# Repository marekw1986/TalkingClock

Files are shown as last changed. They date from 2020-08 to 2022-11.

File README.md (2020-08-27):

# TalkingClock

## Overwiev
This is repository of firmware for Talking Clock project. 
It uses vintage parts, such as WDC65C02 CPU, M6242B RTC, MC6840 timer or R65C51 UART. 
It also consists SP0256-AL2 chip, providing retro speach synthesis capability.

This project is still in development.

## Required tools
You need [cc65](https://github.com/cc65/cc65) to build this project.
Additionaly there are two PLD files, consisting descriptions of address decoders for GAL chips used in this project. 
To synthesise them you need [GalAsm](https://github.com/daveho/GALasm).

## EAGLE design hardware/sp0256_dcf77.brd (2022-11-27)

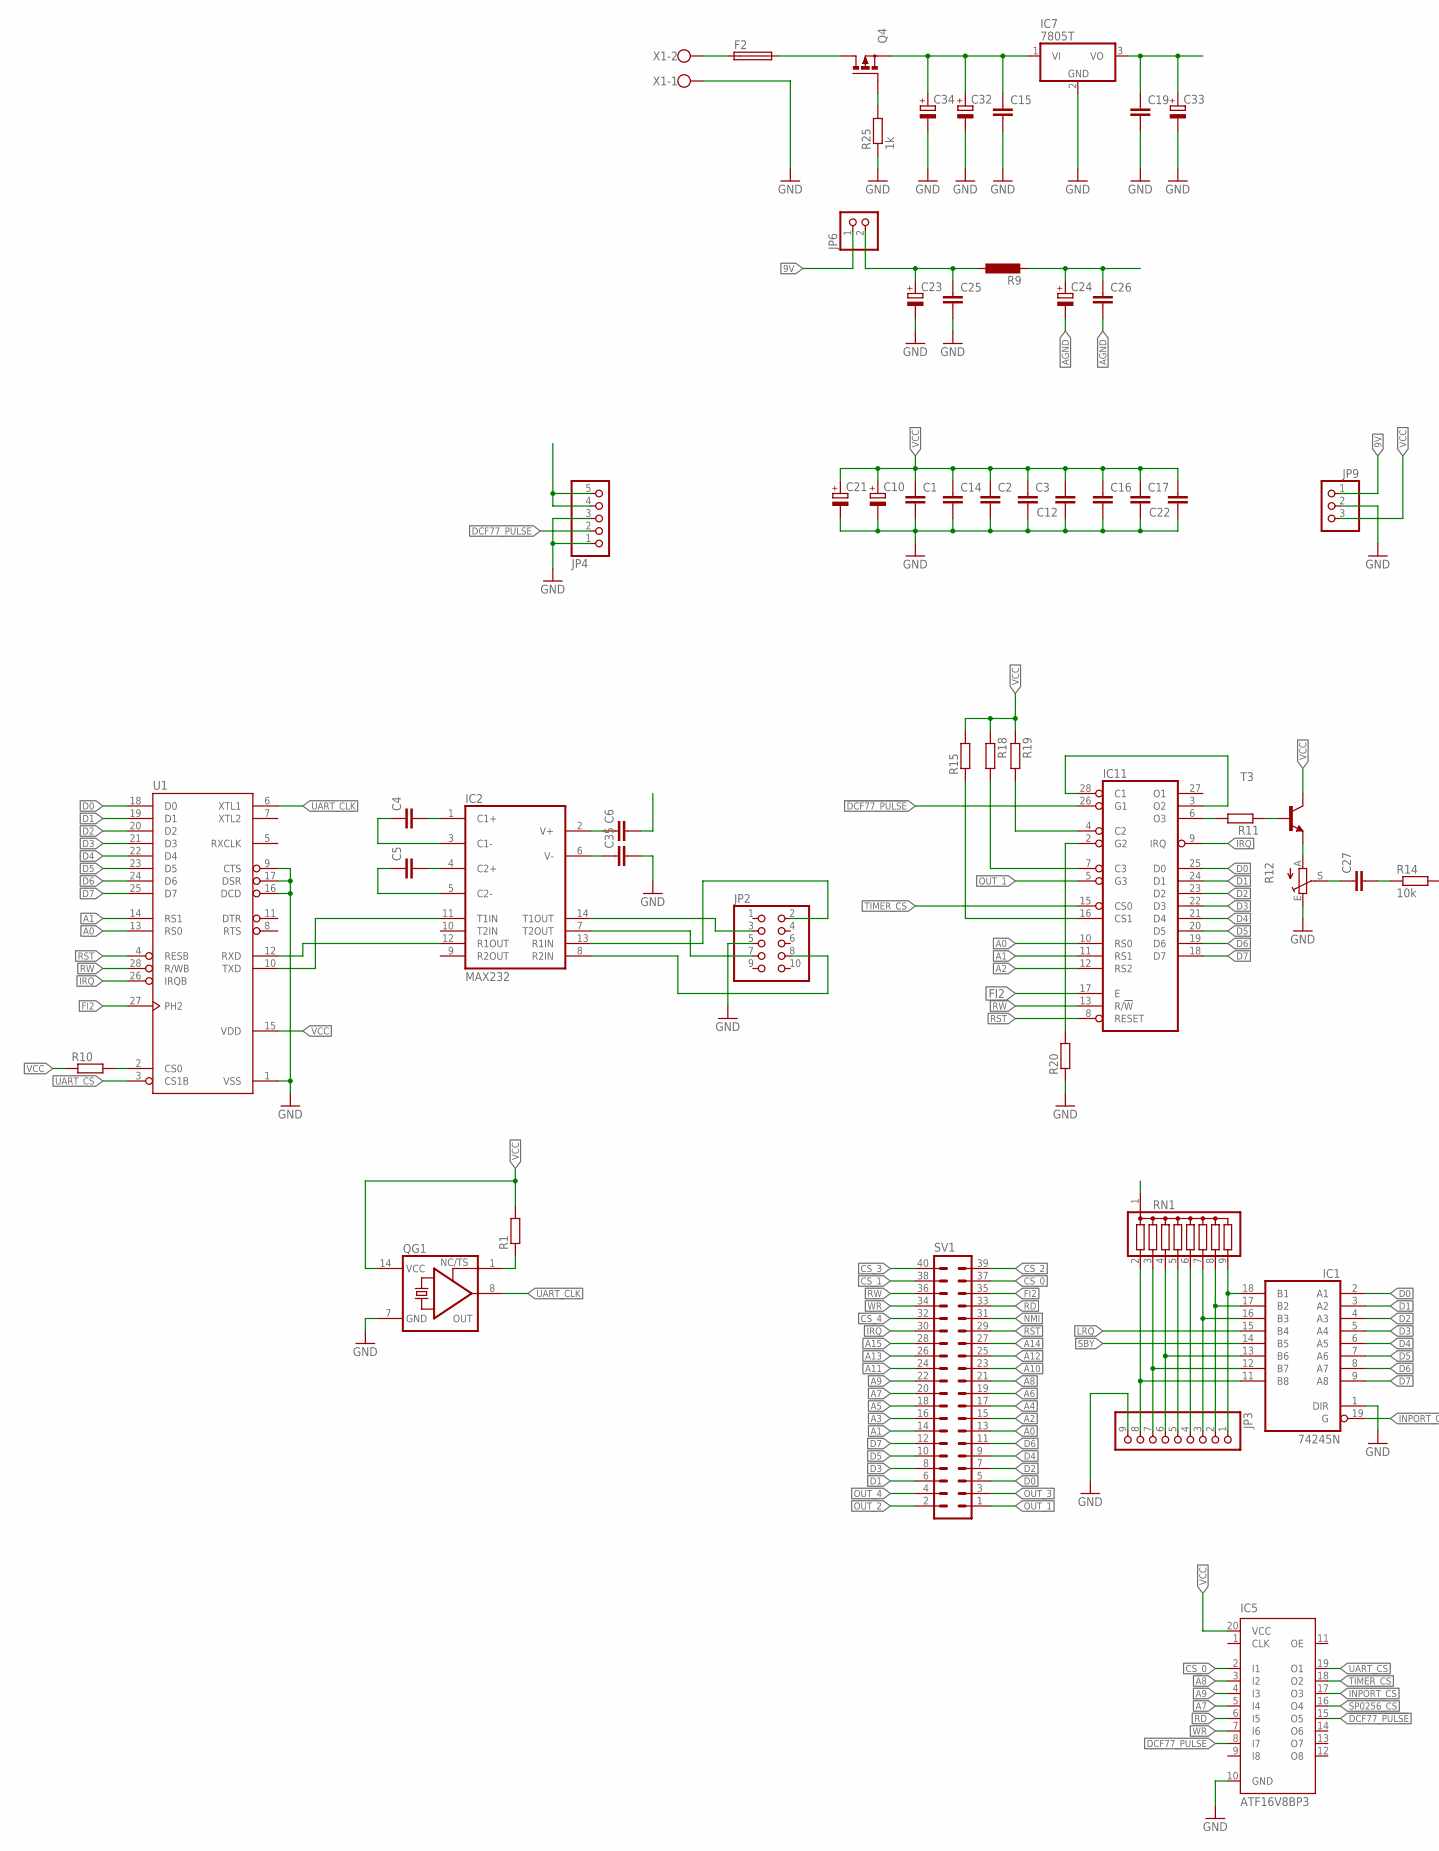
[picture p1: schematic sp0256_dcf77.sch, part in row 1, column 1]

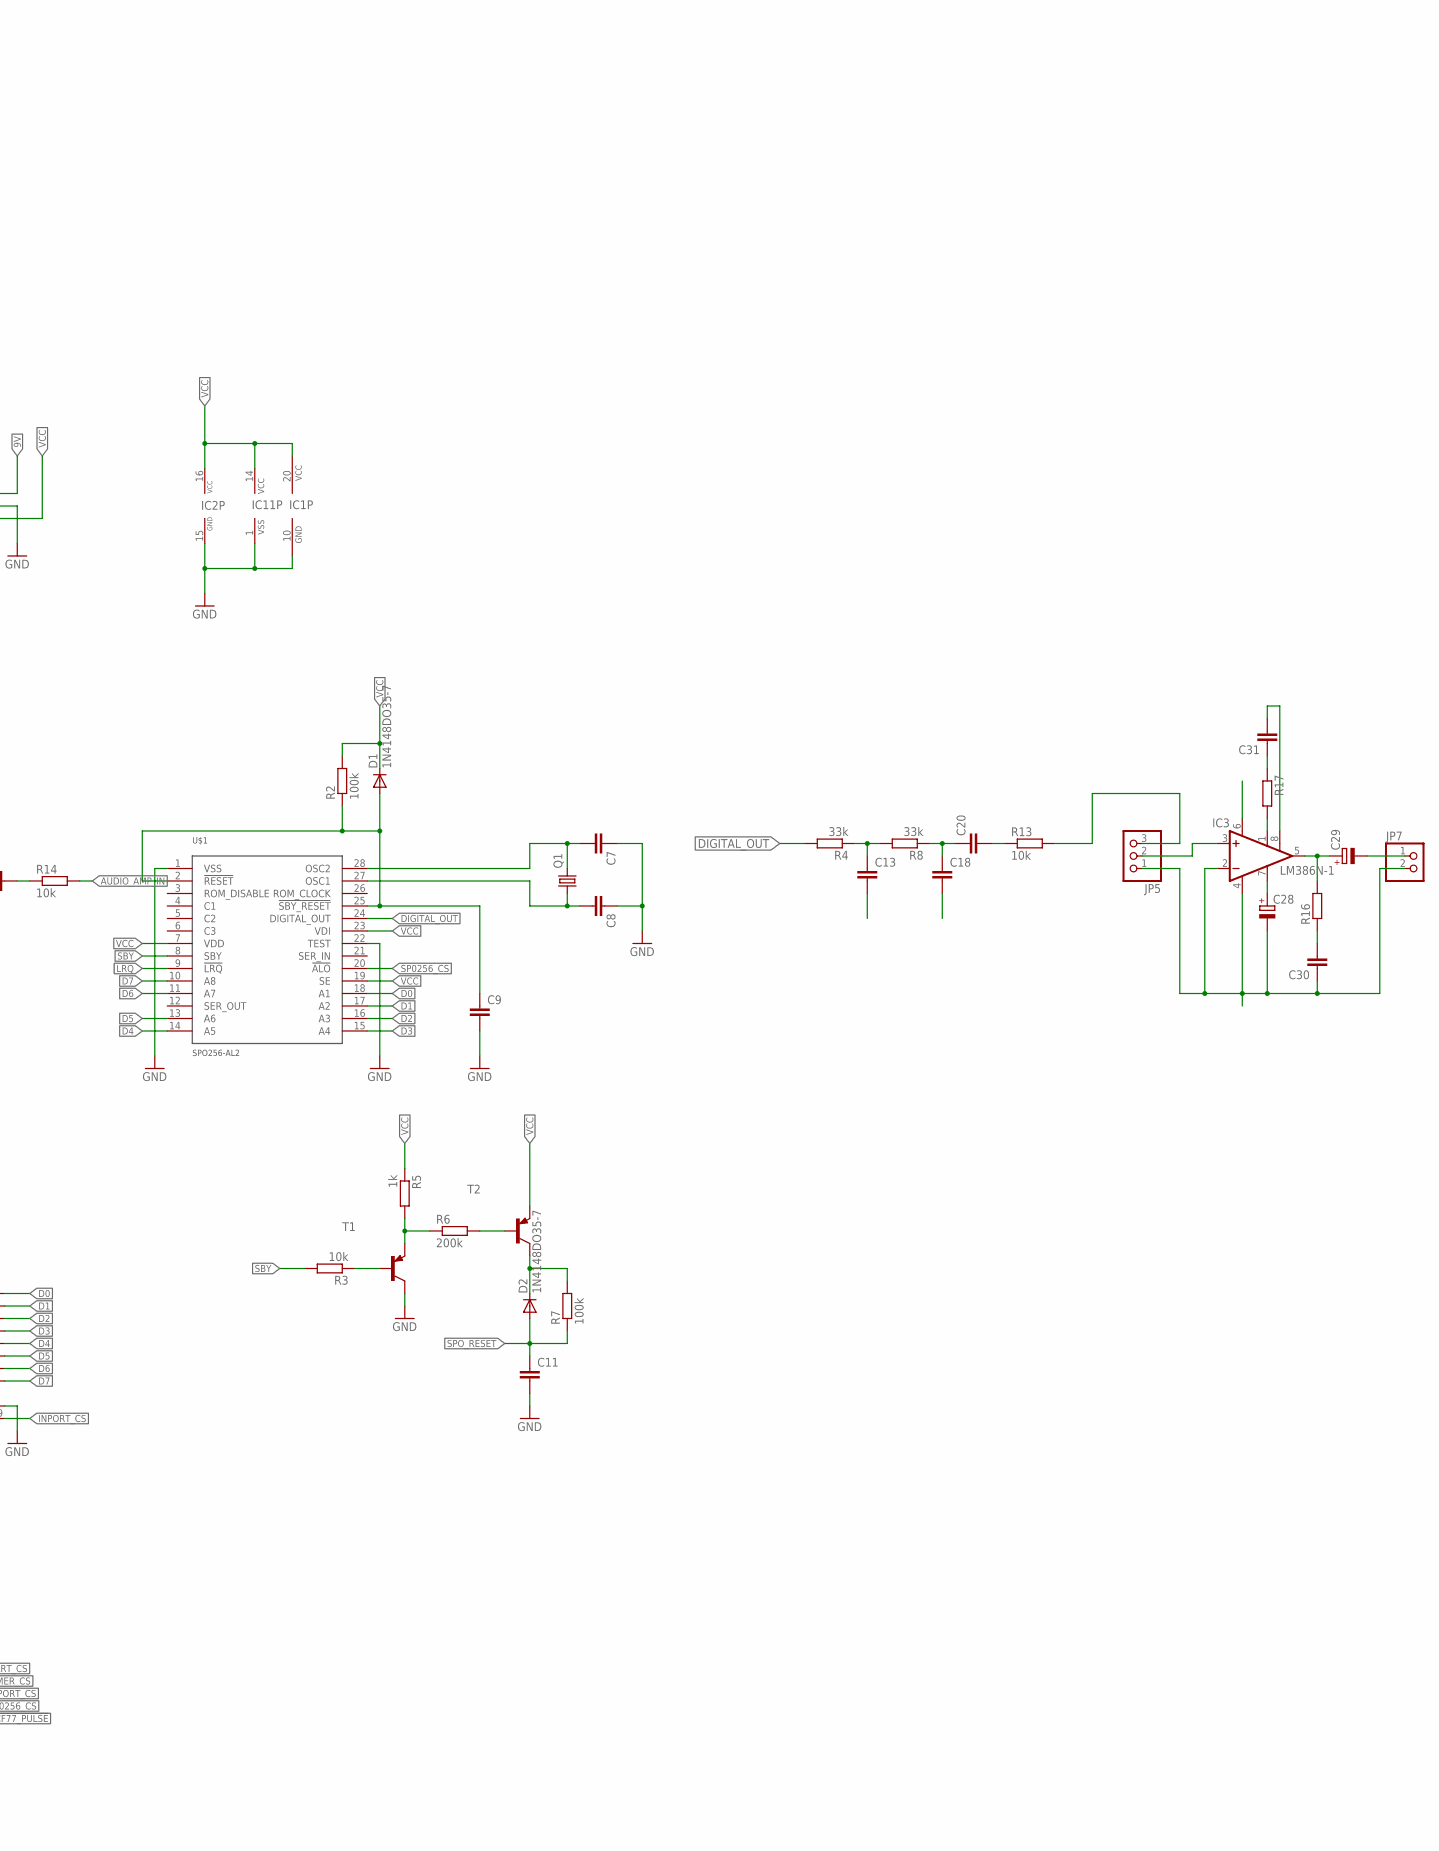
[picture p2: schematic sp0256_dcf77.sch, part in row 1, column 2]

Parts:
C1, C2, C3, C14, C15, C16, C17, C19, C25, C26: C-EUC1206; C1206
C4, C5, C6, C7, C8, C9, C11, C12, C13, C18, C20, C22, C27, C30, C31, C35: C-EUC0603; C0603
C10, C23, C24, C29, C32, C33, C34: CPOL-EUE5-10.5; E5-10,5
C21, C28: CPOL-EUSMCB; SMC_B
D1, D2: 1N4148DO35-7; DO35-7
F2: SH22,5; MPN 0031.8201
IC1: 74245N; DIL20
IC2: MAX232; DIL16
IC3: LM386N-1; DIL08
IC5: ATF16V8BP3; DIL20
IC7: 7805T; TO220H
IC11: 6840; DIL28
JP2: PINHD-2X5; 2X05
JP3: PINHD-1X9; 1X09
JP4: PINHD-1X5; 1X05
JP5: PINHD-1X3; 1X03
JP6, JP7: PINHD-1X2; 1X02
JP9: PINHD-1X3/90; 1X03/90
Q1: CRYSTALHC49U-V; HC49U-V
Q4: P-MOSFET-SO8; SO-08
QG1: XO-14; DIL14S
R1: R-EU_R1206; R1206
R2, R7: 100k; 0204/7
R3: 10k; 0204/7
R4, R8: 33k; 0204/7
R5: 1k; 0204/5
R6: 200k; R0603
R9: L-EU0204/7; 0204/7
R10, R15, R16, R18, R19, R20: R-EU_R0603; R0603
R11, R17: R-EU_0204/7; 0204/7
R12: TRIM_EU-CA6V; CA6V
R13, R14: 10k; R0603
R25: 1k; R0603
RN1: G08R; SIL9
SV1: ML40L
T1, T2: MPS2907A-PNP-TO92-CBE; TO92-CBE
T3: BC550-NPN-TO92-CBE; TO92-CBE
U1: G65SC51P; DIP-28
U$1: SPO256-AL2; DIL28
X1: W237-102

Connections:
9V: C15.1, C32.+, C34.+, IC7.1 (VI), JP6.1, JP9.1, Q4.1 (S), Q4.2 (S), Q4.3 (S)
9V_SW: C23.+, C25.1, JP6.2, R9.1
!DCF77_PULSE: IC5.15 (O5), IC11.26 (G1)
A0: IC11.10 (RS0), SV1.13, U1.13 (RS0)
A1: IC11.11 (RS1), SV1.14, U1.14 (RS1)
A2: IC11.12 (RS2), SV1.15
A3: SV1.16
A4: SV1.17
A5: SV1.18
A6: SV1.19
A7: IC5.5 (I4), SV1.20
A8: IC5.3 (I2), SV1.21
A9: IC5.4 (I3), SV1.22
A10: SV1.23
A11: SV1.24
A12: SV1.25
A13: SV1.26
A14: SV1.27
A15: SV1.28
AGND: C13.2, C18.2, C24.-, C26.2, C28.-, C30.1, IC3.2 (-IN), IC3.4 (GND), JP5.1, JP7.2
AUDIO_AMP_IN: JP5.3, R13.2, R14.2
AVCC: C24.+, C26.1, IC3.6 (VS), R9.2
CS_0: IC5.2 (I1), SV1.37
CS_1: SV1.38
CS_2: SV1.39
CS_3: SV1.40
CS_4: SV1.32
D0: IC1.2 (A1), IC11.25 (D0), SV1.5, U1.18 (D0), U$1.18 (A1)
D1: IC1.3 (A2), IC11.24 (D1), SV1.6, U1.19 (D1), U$1.17 (A2)
D2: IC1.4 (A3), IC11.23 (D2), SV1.7, U1.20 (D2), U$1.16 (A3)
D3: IC1.5 (A4), IC11.22 (D3), SV1.8, U1.21 (D3), U$1.15 (A4)
D4: IC1.6 (A5), IC11.21 (D4), SV1.9, U1.22 (D4), U$1.14 (A5)
D5: IC1.7 (A6), IC11.20 (D5), SV1.10, U1.23 (D5), U$1.13 (A6)
D6: IC1.8 (A7), IC11.19 (D6), SV1.11, U1.24 (D6), U$1.11 (A7)
D7: IC1.9 (A8), IC11.18 (D7), SV1.12, U1.25 (D7), U$1.10 (A8)
DCF77_PULSE: IC5.8 (I7), JP4.2
DIGITAL_OUT: R4.2, U$1.24 (DIGITAL_OUT)
FI2: IC11.17 (E), SV1.35, U1.27 (PH2)
GATE2: IC11.2 (G2), R20.2
GND: C1.2, C2.2, C3.2, C7.1, C8.1, C9.2, C10.-, C11.2, C12.1, C14.2, C15.2, C16.2, C17.2, C19.2, C21.-, C22.1, C23.-, C25.2, C32.-, C33.-, C34.-, C35.2, IC1.1 (DIR), IC1.10 (GND), IC2.15 (GND), IC5.10 (GND), IC7.2 (GND), IC11.1 (VSS), JP2.5, JP3.9, JP4.1, JP4.3, JP9.2, QG1.7 (GND), R12.E, R20.1, R25.1, T1.C, U1.1 (VSS), U1.9 (CTS), U1.16 (DCD), U1.17 (DSR), U$1.1 (VSS), U$1.22 (TEST), X1.1
INPORT_CS: IC1.19 (G), IC5.17 (O3)
IRQ: IC11.9 (IRQ), SV1.30, U1.26 (IRQB)
LRQ: IC1.15 (B4), U$1.9 (!LRQ)
unnamed: Q4.4 (G), R25.2
unnamed: IC11.3 (O2), IC11.28 (C1)
unnamed: C35.1, IC2.6 (V-)
unnamed: QG1.1 (TS), R1.1
unnamed: C7.2, Q1.2, U$1.28 (OSC2)
unnamed: C8.2, Q1.1, U$1.27 (OSC1)
unnamed: R3.1, T1.B
unnamed: C4.2, IC2.1 (C1+)
unnamed: C5.2, IC2.4 (C2+)
unnamed: C5.1, IC2.5 (C2-)
unnamed: C4.1, IC2.3 (C1-)
unnamed: C6.1, IC2.2 (V+)
unnamed: IC1.18 (B1), JP3.1, RN1.9
unnamed: IC1.17 (B2), JP3.2, RN1.8
unnamed: IC1.16 (B3), JP3.3, RN1.7
unnamed: C13.1, R4.1, R8.2
unnamed: JP3.5, RN1.5
unnamed: IC1.13 (B6), JP3.6, RN1.4
unnamed: IC1.12 (B7), JP3.7, RN1.3
unnamed: IC1.11 (B8), JP3.8, RN1.2
unnamed: JP3.4, RN1.6
unnamed: R10.2, U1.2 (CS0)
unnamed: R5.2, R6.1, T1.E
unnamed: R6.2, T2.B
unnamed: D2.C, R7.2, T2.C
unnamed: IC11.16 (CS1), R15.1
unnamed: C18.1, C20.1, R8.1
unnamed: C28.+, IC3.7 (BYPASS)
unnamed: IC11.7 (C3), R18.2
unnamed: IC11.6 (O3), R11.2
unnamed: R11.1, T3.B
unnamed: R12.A, T3.E
unnamed: C27.1, R12.S
unnamed: C27.2, R14.1
unnamed: C20.2, R13.1
unnamed: IC3.3 (+IN), JP5.2
unnamed: C29.+, IC3.5 (OUT), R16.2
unnamed: C30.2, R16.1
unnamed: IC3.1 (GAIN), R17.2
unnamed: C31.1, R17.1
unnamed: C31.2, IC3.8 (GAIN)
unnamed: C29.-, JP7.1
unnamed: IC11.4 (C2), R19.2
unnamed: F2.2, Q4.5 (D), Q4.6 (D), Q4.7 (D), Q4.8 (D)
unnamed: F2.1, X1.2
NMI: SV1.31
OUT_1: IC11.5 (G3), SV1.1
OUT_2: SV1.2
OUT_3: SV1.3
OUT_4: SV1.4
RD: IC5.6 (I5), SV1.33
RST: IC11.8 (RESET), SV1.29, U1.4 (RESB)
RS_CTS: IC2.8 (R2IN), JP2.8
RS_RTS: IC2.7 (T2OUT), JP2.7
RS_RXD: IC2.13 (R1IN), JP2.2
RS_TXD: IC2.14 (T1OUT), JP2.3
RW: IC11.13 (R/!W), SV1.36, U1.28 (R/WB)
RXD_TTL: IC2.12 (R1OUT), U1.12 (RXD)
SBY: IC1.14 (B5), R3.2, U$1.8 (SBY)
SP0256_CS: IC5.16 (O4), U$1.20 (!ALO)
SPO_RESET: C9.1, C11.1, D1.A, D2.A, R2.1, R7.1, U$1.2 (!RESET), U$1.25 (!SBY_RESET)
TIMER_CS: IC5.18 (O2), IC11.15 (CS0)
TXD_TTL: IC2.11 (T1IN), U1.10 (TXD)
UART_CLK: QG1.8 (OUT), U1.6 (XTL1)
UART_CS: IC5.19 (O1), U1.3 (CS1B)
VCC: C1.1, C2.1, C3.1, C6.2, C10.+, C12.2, C14.1, C16.1, C17.1, C19.1, C21.+, C22.2, C33.+, D1.C, IC1.20 (VCC), IC2.16 (VCC), IC5.20 (VCC), IC7.3 (VO), IC11.14 (VCC), JP4.4, JP4.5, JP9.3, QG1.14 (VCC), R1.2, R2.2, R5.1, R10.1, R15.2, R18.1, R19.1, RN1.1, T2.E, T3.C, U1.15 (VDD), U$1.7 (VDD), U$1.19 (SE), U$1.23 (VDI)
WR: IC5.7 (I6), SV1.34

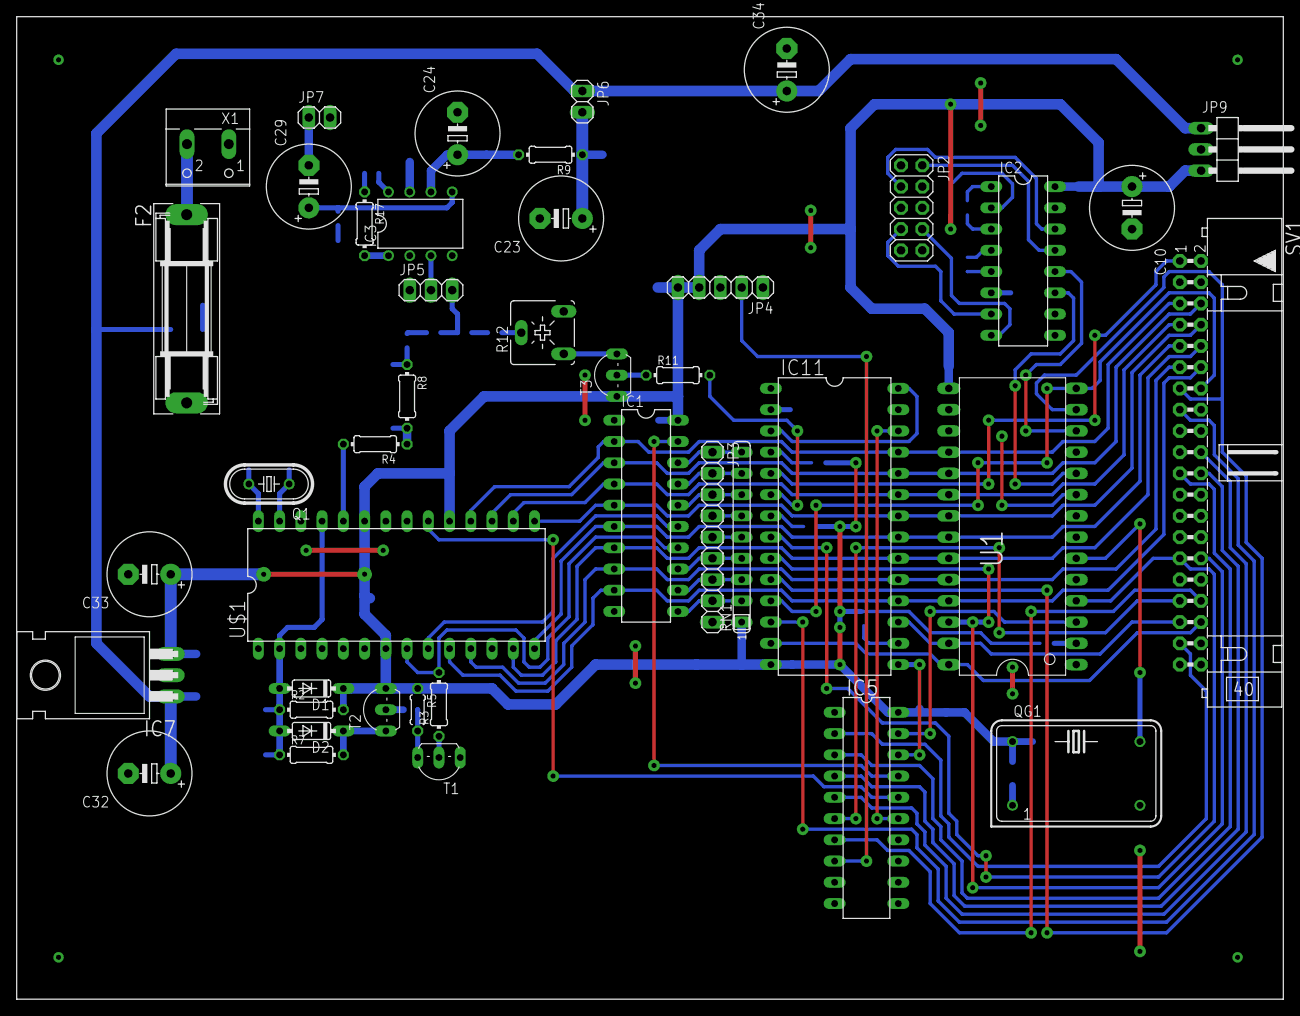
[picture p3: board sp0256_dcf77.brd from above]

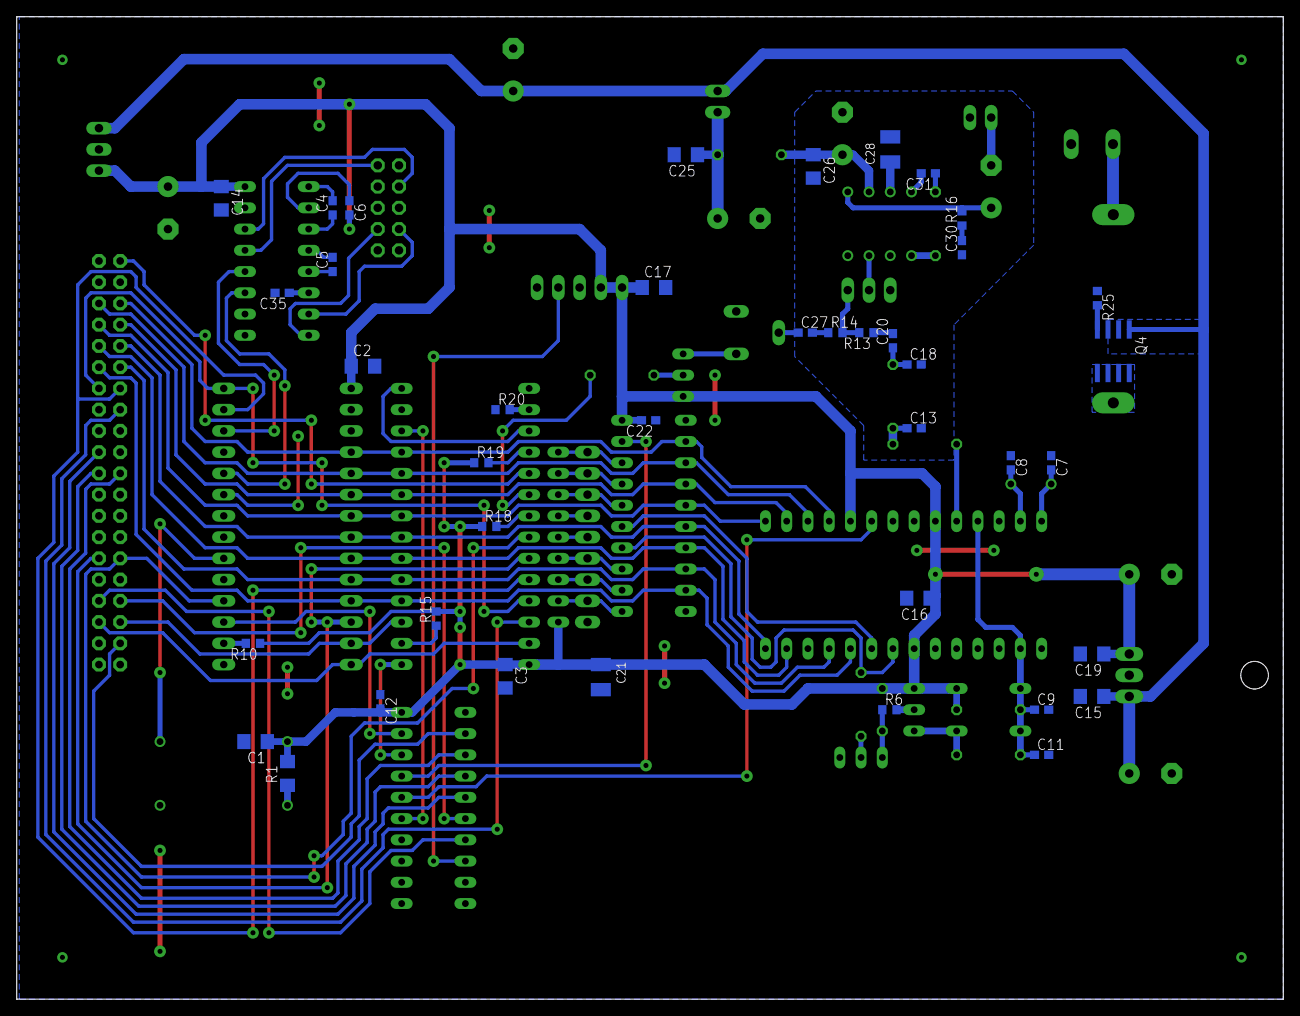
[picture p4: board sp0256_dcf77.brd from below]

Board: 2 copper layers, 151.4 x 117.5 mm, 83 parts (40 on the bottom side), 92 nets.

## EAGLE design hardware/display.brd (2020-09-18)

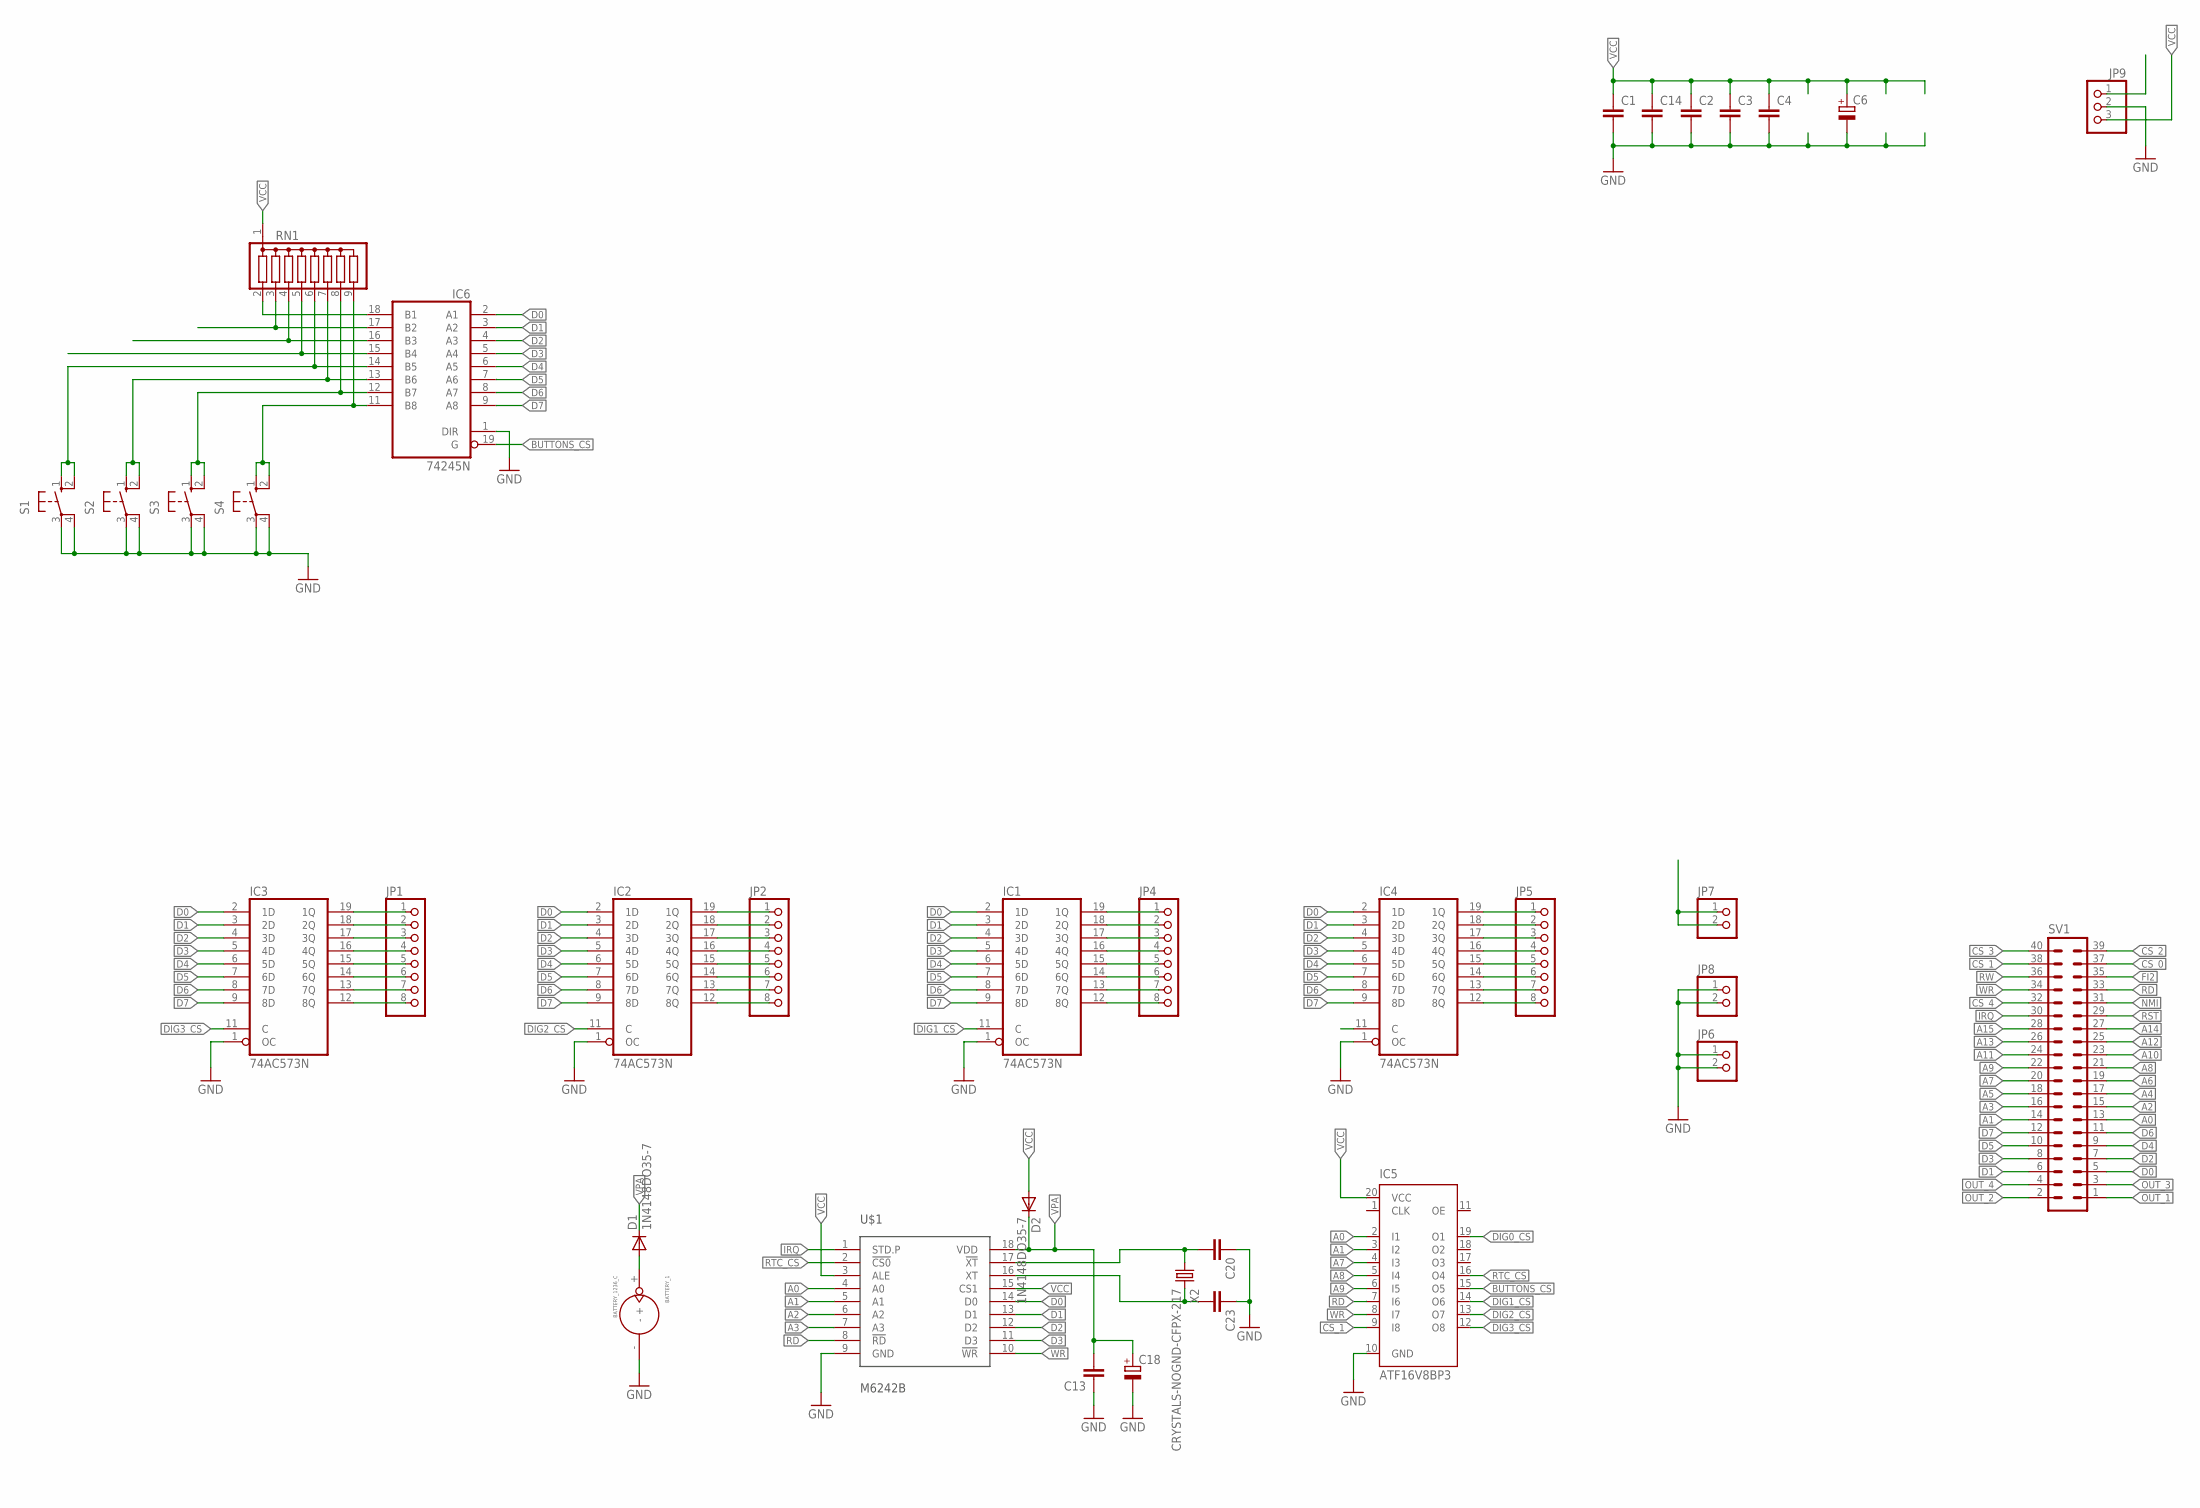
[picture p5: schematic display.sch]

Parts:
BATTERY_1: BATTERY_1236_C
C1, C2, C3, C4, C14: C-EUC1206; C1206
C6: CPOL-EUSMCD; SMC_D
C13, C20, C23: C-EUC0603; C0603
C18: CPOL-EUSMCB; SMC_B
D1, D2: 1N4148DO35-7; DO35-7
IC1, IC2, IC3, IC4: 74AC573N; DIL20
IC5: ATF16V8BP3; DIL20
IC6: 74245N; DIL20
JP1, JP2, JP4, JP5: PINHD-1X8; 1X08
JP6, JP7, JP8: PINHD-1X2; 1X02
JP9: PINHD-1X3/90; 1X03/90
RN1: G08R; SIL9
S1, S2, S3, S4: 40-XX; B3F-40XX
SV1: ML40L
U$1: M6242B; DIL18
X2: CRYSTALS-NOGND-CFPX-217; 3.2X1.5-2-PAD

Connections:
9V: JP7.1, JP7.2, JP9.1
A0: IC5.2 (I1), SV1.13, U$1.4 (A0)
A1: IC5.3 (I2), SV1.14, U$1.5 (A1)
A2: SV1.15, U$1.6 (A2)
A3: SV1.16, U$1.7 (A3)
A4: SV1.17
A5: SV1.18
A6: SV1.19
A7: IC5.4 (I3), SV1.20
A8: IC5.5 (I4), SV1.21
A9: IC5.6 (I5), SV1.22
A10: SV1.23
A11: SV1.24
A12: SV1.25
A13: SV1.26
A14: SV1.27
A15: SV1.28
BUTTONS_CS: IC5.15 (O5), IC6.19 (G)
CS_0: SV1.37
CS_1: IC5.9 (I8), SV1.38
CS_2: SV1.39
CS_3: SV1.40
CS_4: SV1.32
D0: IC1.2 (1D), IC2.2 (1D), IC3.2 (1D), IC4.2 (1D), IC6.2 (A1), SV1.5, U$1.14 (D0)
D1: IC1.3 (2D), IC2.3 (2D), IC3.3 (2D), IC4.3 (2D), IC6.3 (A2), SV1.6, U$1.13 (D1)
D2: IC1.4 (3D), IC2.4 (3D), IC3.4 (3D), IC4.4 (3D), IC6.4 (A3), SV1.7, U$1.12 (D2)
D3: IC1.5 (4D), IC2.5 (4D), IC3.5 (4D), IC4.5 (4D), IC6.5 (A4), SV1.8, U$1.11 (D3)
D4: IC1.6 (5D), IC2.6 (5D), IC3.6 (5D), IC4.6 (5D), IC6.6 (A5), SV1.9
D5: IC1.7 (6D), IC2.7 (6D), IC3.7 (6D), IC4.7 (6D), IC6.7 (A6), SV1.10
D6: IC1.8 (7D), IC2.8 (7D), IC3.8 (7D), IC4.8 (7D), IC6.8 (A7), SV1.11
D7: IC1.9 (8D), IC2.9 (8D), IC3.9 (8D), IC4.9 (8D), IC6.9 (A8), SV1.12
DIG0_CS: IC4.11 (C), IC5.19 (O1)
DIG1_CS: IC1.11 (C), IC5.14 (O6)
DIG2_CS: IC2.11 (C), IC5.13 (O7)
DIG3_CS: IC3.11 (C), IC5.12 (O8)
FI2: SV1.35
GND: BATTERY_1.-, C1.2, C2.2, C3.2, C4.2, C6.-, C13.1, C14.2, C18.-, C20.1, C23.1, IC1.1 (OC), IC1.10 (GND), IC2.1 (OC), IC2.10 (GND), IC3.1 (OC), IC3.10 (GND), IC4.1 (OC), IC4.10 (GND), IC5.10 (GND), IC6.1 (DIR), IC6.10 (GND), JP6.1, JP6.2, JP8.1, JP8.2, JP9.2, S1.3, S1.4 (P1), S2.3, S2.4 (P1), S3.3, S3.4 (P1), S4.3, S4.4 (P1), U$1.9 (GND)
IRQ: SV1.30, U$1.1 (STD.P)
unnamed: IC3.12 (8Q), JP1.8
unnamed: IC3.13 (7Q), JP1.7
unnamed: IC3.14 (6Q), JP1.6
unnamed: IC3.19 (1Q), JP1.1
unnamed: IC3.18 (2Q), JP1.2
unnamed: IC3.17 (3Q), JP1.3
unnamed: IC3.16 (4Q), JP1.4
unnamed: IC3.15 (5Q), JP1.5
unnamed: IC2.17 (3Q), JP2.3
unnamed: IC2.18 (2Q), JP2.2
unnamed: IC2.19 (1Q), JP2.1
unnamed: IC2.16 (4Q), JP2.4
unnamed: IC2.15 (5Q), JP2.5
unnamed: IC2.14 (6Q), JP2.6
unnamed: IC2.13 (7Q), JP2.7
unnamed: IC2.12 (8Q), JP2.8
unnamed: IC1.19 (1Q), JP4.1
unnamed: IC1.18 (2Q), JP4.2
unnamed: IC1.17 (3Q), JP4.3
unnamed: IC1.16 (4Q), JP4.4
unnamed: IC1.15 (5Q), JP4.5
unnamed: IC1.14 (6Q), JP4.6
unnamed: IC1.13 (7Q), JP4.7
unnamed: IC1.12 (8Q), JP4.8
unnamed: IC4.17 (3Q), JP5.3
unnamed: IC4.19 (1Q), JP5.1
unnamed: IC4.18 (2Q), JP5.2
unnamed: IC4.16 (4Q), JP5.4
unnamed: IC4.15 (5Q), JP5.5
unnamed: IC4.14 (6Q), JP5.6
unnamed: IC4.13 (7Q), JP5.7
unnamed: IC4.12 (8Q), JP5.8
unnamed: BATTERY_1.+, D1.A
unnamed: IC6.14 (B5), RN1.6, S1.1 (S), S1.2 (S1)
unnamed: IC6.13 (B6), RN1.7, S2.1 (S), S2.2 (S1)
unnamed: IC6.12 (B7), RN1.8, S3.1 (S), S3.2 (S1)
unnamed: IC6.11 (B8), RN1.9, S4.1 (S), S4.2 (S1)
NMI: SV1.31
OUT_1: SV1.1
OUT_2: SV1.2
OUT_3: SV1.3
OUT_4: SV1.4
RD: IC5.7 (I6), SV1.33, U$1.8 (!RD)
RST: SV1.29
RTC_CS: IC5.16 (O4), U$1.2 (!CS0)
RW: SV1.36
S1: IC6.15 (B4), RN1.5
S2: IC6.16 (B3), RN1.4
S3: IC6.17 (B2), RN1.3
S4: IC6.18 (B1), RN1.2
SOSCI: C20.2, U$1.17 (!XT), X2.1
SOSCO: C23.2, U$1.16 (XT), X2.2
VCC: C1.1, C2.1, C3.1, C4.1, C6.+, C14.1, D2.A, IC1.20 (VCC), IC2.20 (VCC), IC3.20 (VCC), IC4.20 (VCC), IC5.20 (VCC), IC6.20 (VCC), JP9.3, RN1.1, U$1.3 (ALE), U$1.15 (CS1)
VPA: C13.2, C18.+, D1.C, D2.C, U$1.18 (VDD)
WR: IC5.8 (I7), SV1.34, U$1.10 (!WR)

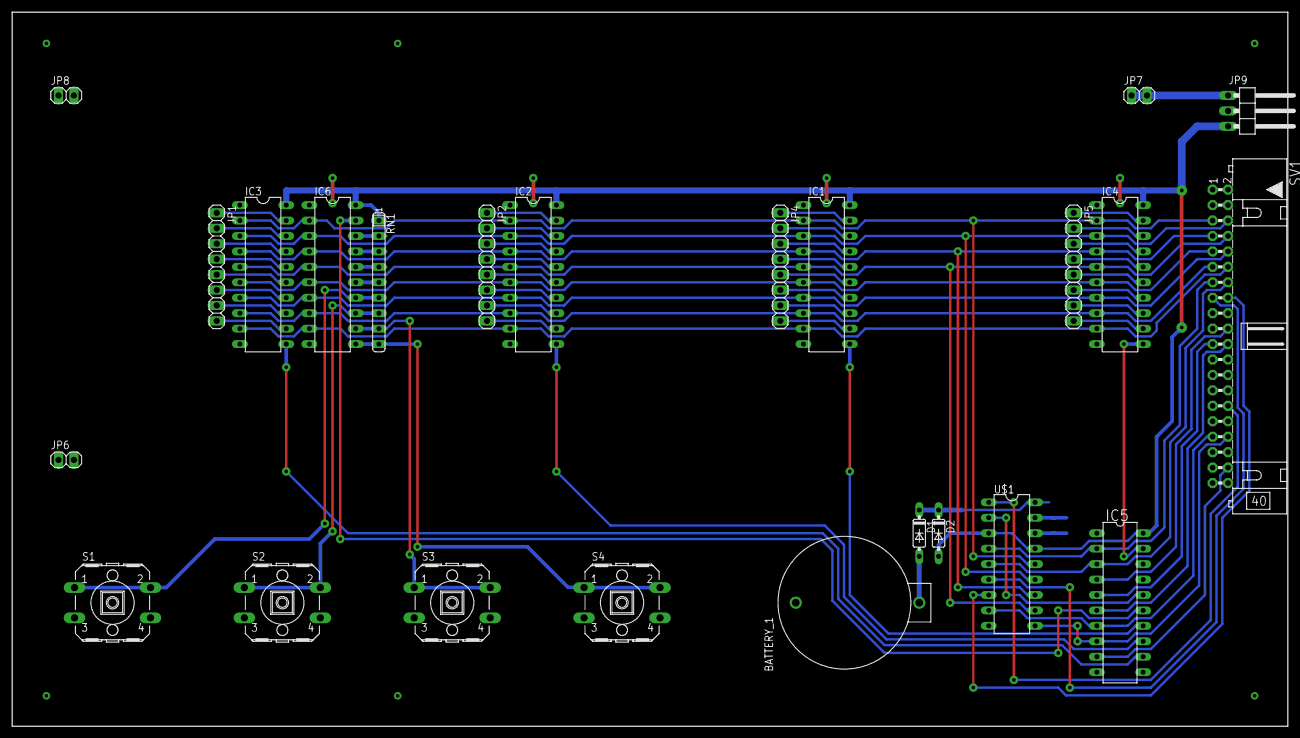
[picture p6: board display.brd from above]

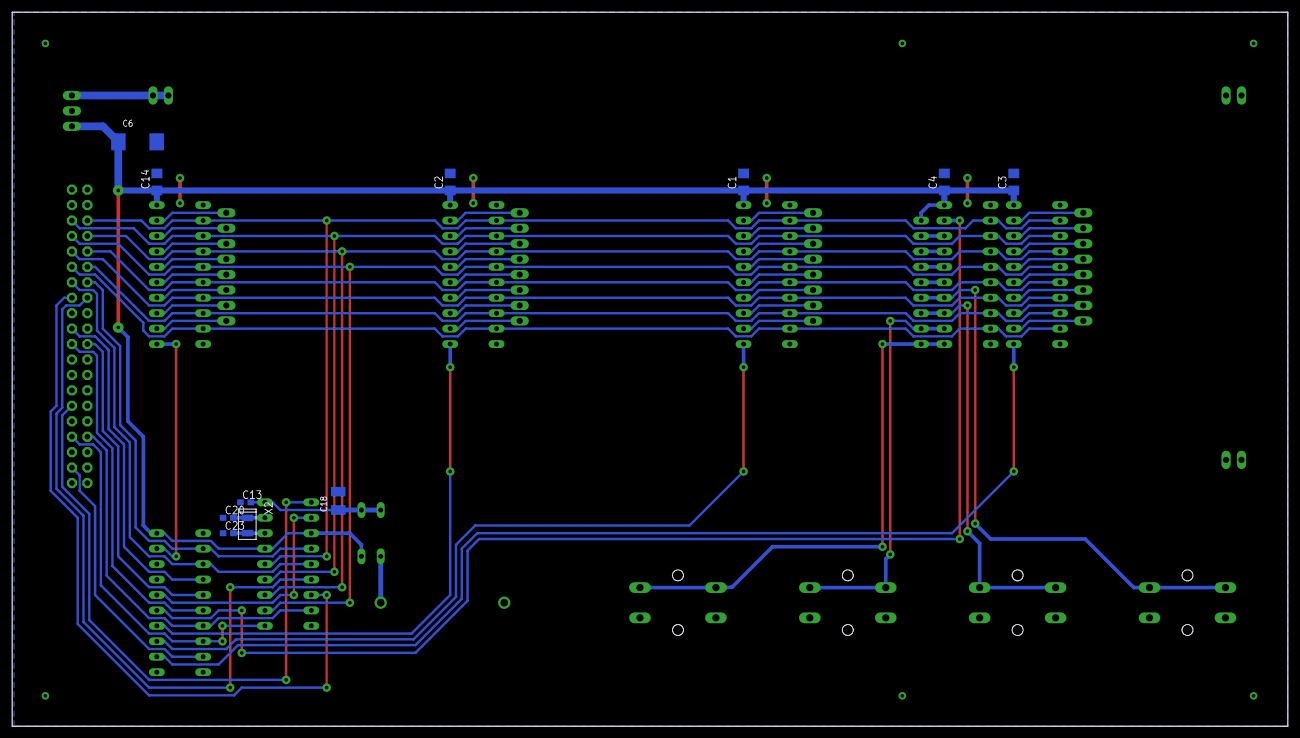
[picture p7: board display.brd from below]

Board: 2 copper layers, 209.9 x 117.5 mm, 35 parts (11 on the bottom side), 72 nets.

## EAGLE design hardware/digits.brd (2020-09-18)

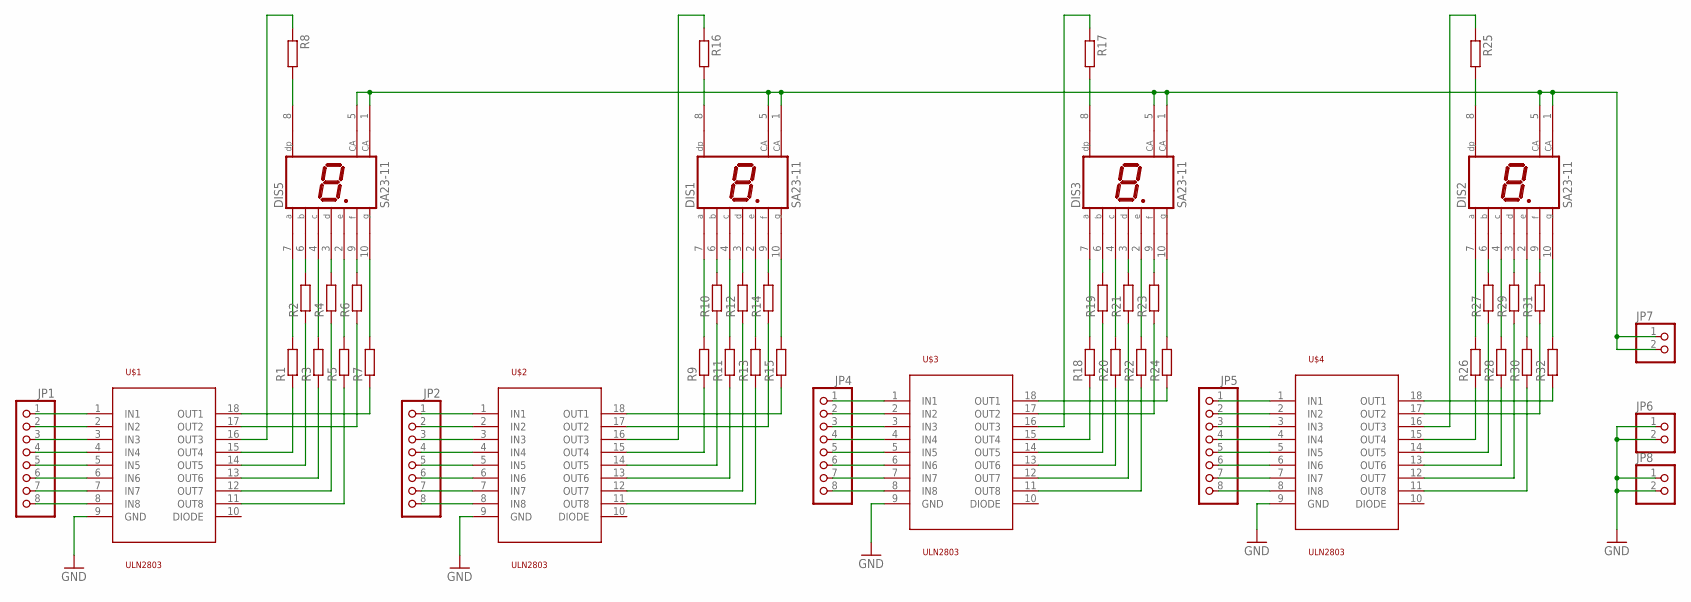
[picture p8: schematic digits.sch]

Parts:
DIS1, DIS2, DIS3, DIS5: SA23-11; SX23-XX
JP1, JP2, JP4, JP5: PINHD-1X8; 1X08
JP6, JP7, JP8: PINHD-1X2; 1X02
R1, R2, R6, R7, R8, R9, R10, R14, R15, R16, R17, R18, R19, R23, R24, R25, R26, R27, R31, R32: R-EU_R0603; R0603
R3, R4, R5, R11, R12, R13, R20, R21, R22, R28, R29, R30: R-EU_0204/7; 0204/7
U$1, U$2, U$3, U$4: ULN2803; SO18L

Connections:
9V: DIS1.1 (CA), DIS1.5 (CA), DIS2.1 (CA), DIS2.5 (CA), DIS3.1 (CA), DIS3.5 (CA), DIS5.1 (CA), DIS5.5 (CA), JP7.1, JP7.2
GND: JP6.1, JP6.2, JP8.1, JP8.2, U$1.9 (GND), U$2.9 (GND), U$3.9 (GND), U$4.9 (GND)
unnamed: DIS5.7 (A), R1.2
unnamed: DIS5.6 (B), R2.2
unnamed: JP1.8, U$1.8 (IN8)
unnamed: JP1.7, U$1.7 (IN7)
unnamed: JP1.6, U$1.6 (IN6)
unnamed: JP1.1, U$1.1 (IN1)
unnamed: JP1.2, U$1.2 (IN2)
unnamed: JP1.3, U$1.3 (IN3)
unnamed: JP1.4, U$1.4 (IN4)
unnamed: JP1.5, U$1.5 (IN5)
unnamed: DIS5.4 (C), R3.2
unnamed: DIS5.3 (D), R4.2
unnamed: DIS5.2 (E), R5.2
unnamed: DIS5.9 (F), R6.2
unnamed: DIS5.10 (G), R7.2
unnamed: DIS5.8 (DP), R8.2
unnamed: DIS1.7 (A), R9.2
unnamed: DIS1.4 (C), R11.2
unnamed: DIS1.2 (E), R13.2
unnamed: DIS1.10 (G), R15.2
unnamed: DIS1.6 (B), R10.2
unnamed: DIS1.3 (D), R12.2
unnamed: DIS1.9 (F), R14.2
unnamed: DIS1.8 (DP), R16.2
unnamed: DIS3.8 (DP), R17.2
unnamed: DIS3.7 (A), R18.2
unnamed: DIS3.4 (C), R20.2
unnamed: JP2.3, U$2.3 (IN3)
unnamed: JP2.2, U$2.2 (IN2)
unnamed: JP2.1, U$2.1 (IN1)
unnamed: JP2.4, U$2.4 (IN4)
unnamed: JP2.5, U$2.5 (IN5)
unnamed: JP2.6, U$2.6 (IN6)
unnamed: JP2.7, U$2.7 (IN7)
unnamed: JP2.8, U$2.8 (IN8)
unnamed: JP4.1, U$3.1 (IN1)
unnamed: DIS3.2 (E), R22.2
unnamed: JP4.2, U$3.2 (IN2)
unnamed: JP4.3, U$3.3 (IN3)
unnamed: DIS3.10 (G), R24.2
unnamed: DIS3.6 (B), R19.2
unnamed: DIS3.3 (D), R21.2
unnamed: DIS3.9 (F), R23.2
unnamed: DIS2.8 (DP), R25.2
unnamed: DIS2.7 (A), R26.2
unnamed: DIS2.4 (C), R28.2
unnamed: DIS2.2 (E), R30.2
unnamed: JP4.4, U$3.4 (IN4)
unnamed: JP4.5, U$3.5 (IN5)
unnamed: JP4.6, U$3.6 (IN6)
unnamed: JP4.7, U$3.7 (IN7)
unnamed: JP4.8, U$3.8 (IN8)
unnamed: DIS2.10 (G), R32.2
unnamed: DIS2.6 (B), R27.2
unnamed: DIS2.3 (D), R29.2
unnamed: DIS2.9 (F), R31.2
unnamed: R5.1, U$1.11 (OUT8)
unnamed: R4.1, U$1.12 (OUT7)
unnamed: R3.1, U$1.13 (OUT6)
unnamed: R2.1, U$1.14 (OUT5)
unnamed: JP5.3, U$4.3 (IN3)
unnamed: JP5.1, U$4.1 (IN1)
unnamed: JP5.2, U$4.2 (IN2)
unnamed: JP5.4, U$4.4 (IN4)
unnamed: JP5.5, U$4.5 (IN5)
unnamed: JP5.6, U$4.6 (IN6)
unnamed: JP5.7, U$4.7 (IN7)
unnamed: JP5.8, U$4.8 (IN8)
unnamed: R1.1, U$1.15 (OUT4)
unnamed: R8.1, U$1.16 (OUT3)
unnamed: R6.1, U$1.17 (OUT2)
unnamed: R7.1, U$1.18 (OUT1)
unnamed: R15.1, U$2.18 (OUT1)
unnamed: R14.1, U$2.17 (OUT2)
unnamed: R16.1, U$2.16 (OUT3)
unnamed: R9.1, U$2.15 (OUT4)
unnamed: R10.1, U$2.14 (OUT5)
unnamed: R11.1, U$2.13 (OUT6)
unnamed: R12.1, U$2.12 (OUT7)
unnamed: R13.1, U$2.11 (OUT8)
unnamed: R24.1, U$3.18 (OUT1)
unnamed: R23.1, U$3.17 (OUT2)
unnamed: R17.1, U$3.16 (OUT3)
unnamed: R18.1, U$3.15 (OUT4)
unnamed: R19.1, U$3.14 (OUT5)
unnamed: R20.1, U$3.13 (OUT6)
unnamed: R21.1, U$3.12 (OUT7)
unnamed: R22.1, U$3.11 (OUT8)
unnamed: R32.1, U$4.18 (OUT1)
unnamed: R31.1, U$4.17 (OUT2)
unnamed: R25.1, U$4.16 (OUT3)
unnamed: R26.1, U$4.15 (OUT4)
unnamed: R27.1, U$4.14 (OUT5)
unnamed: R28.1, U$4.13 (OUT6)
unnamed: R29.1, U$4.12 (OUT7)
unnamed: R30.1, U$4.11 (OUT8)

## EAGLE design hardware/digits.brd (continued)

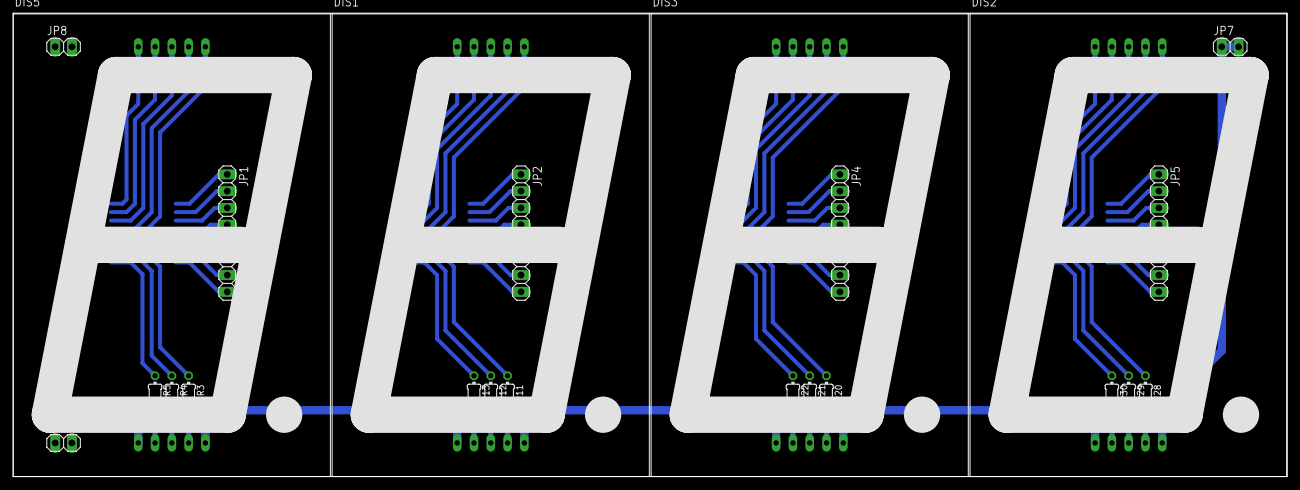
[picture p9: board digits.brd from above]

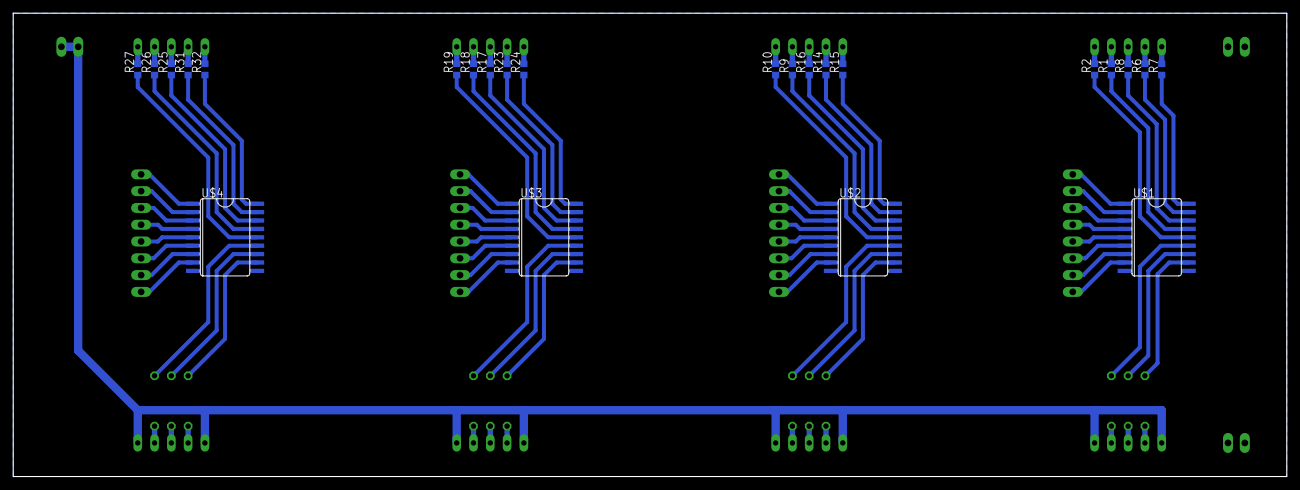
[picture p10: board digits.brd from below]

Board: 2 copper layers, 192.7 x 70.1 mm, 47 parts (24 on the bottom side), 98 nets.

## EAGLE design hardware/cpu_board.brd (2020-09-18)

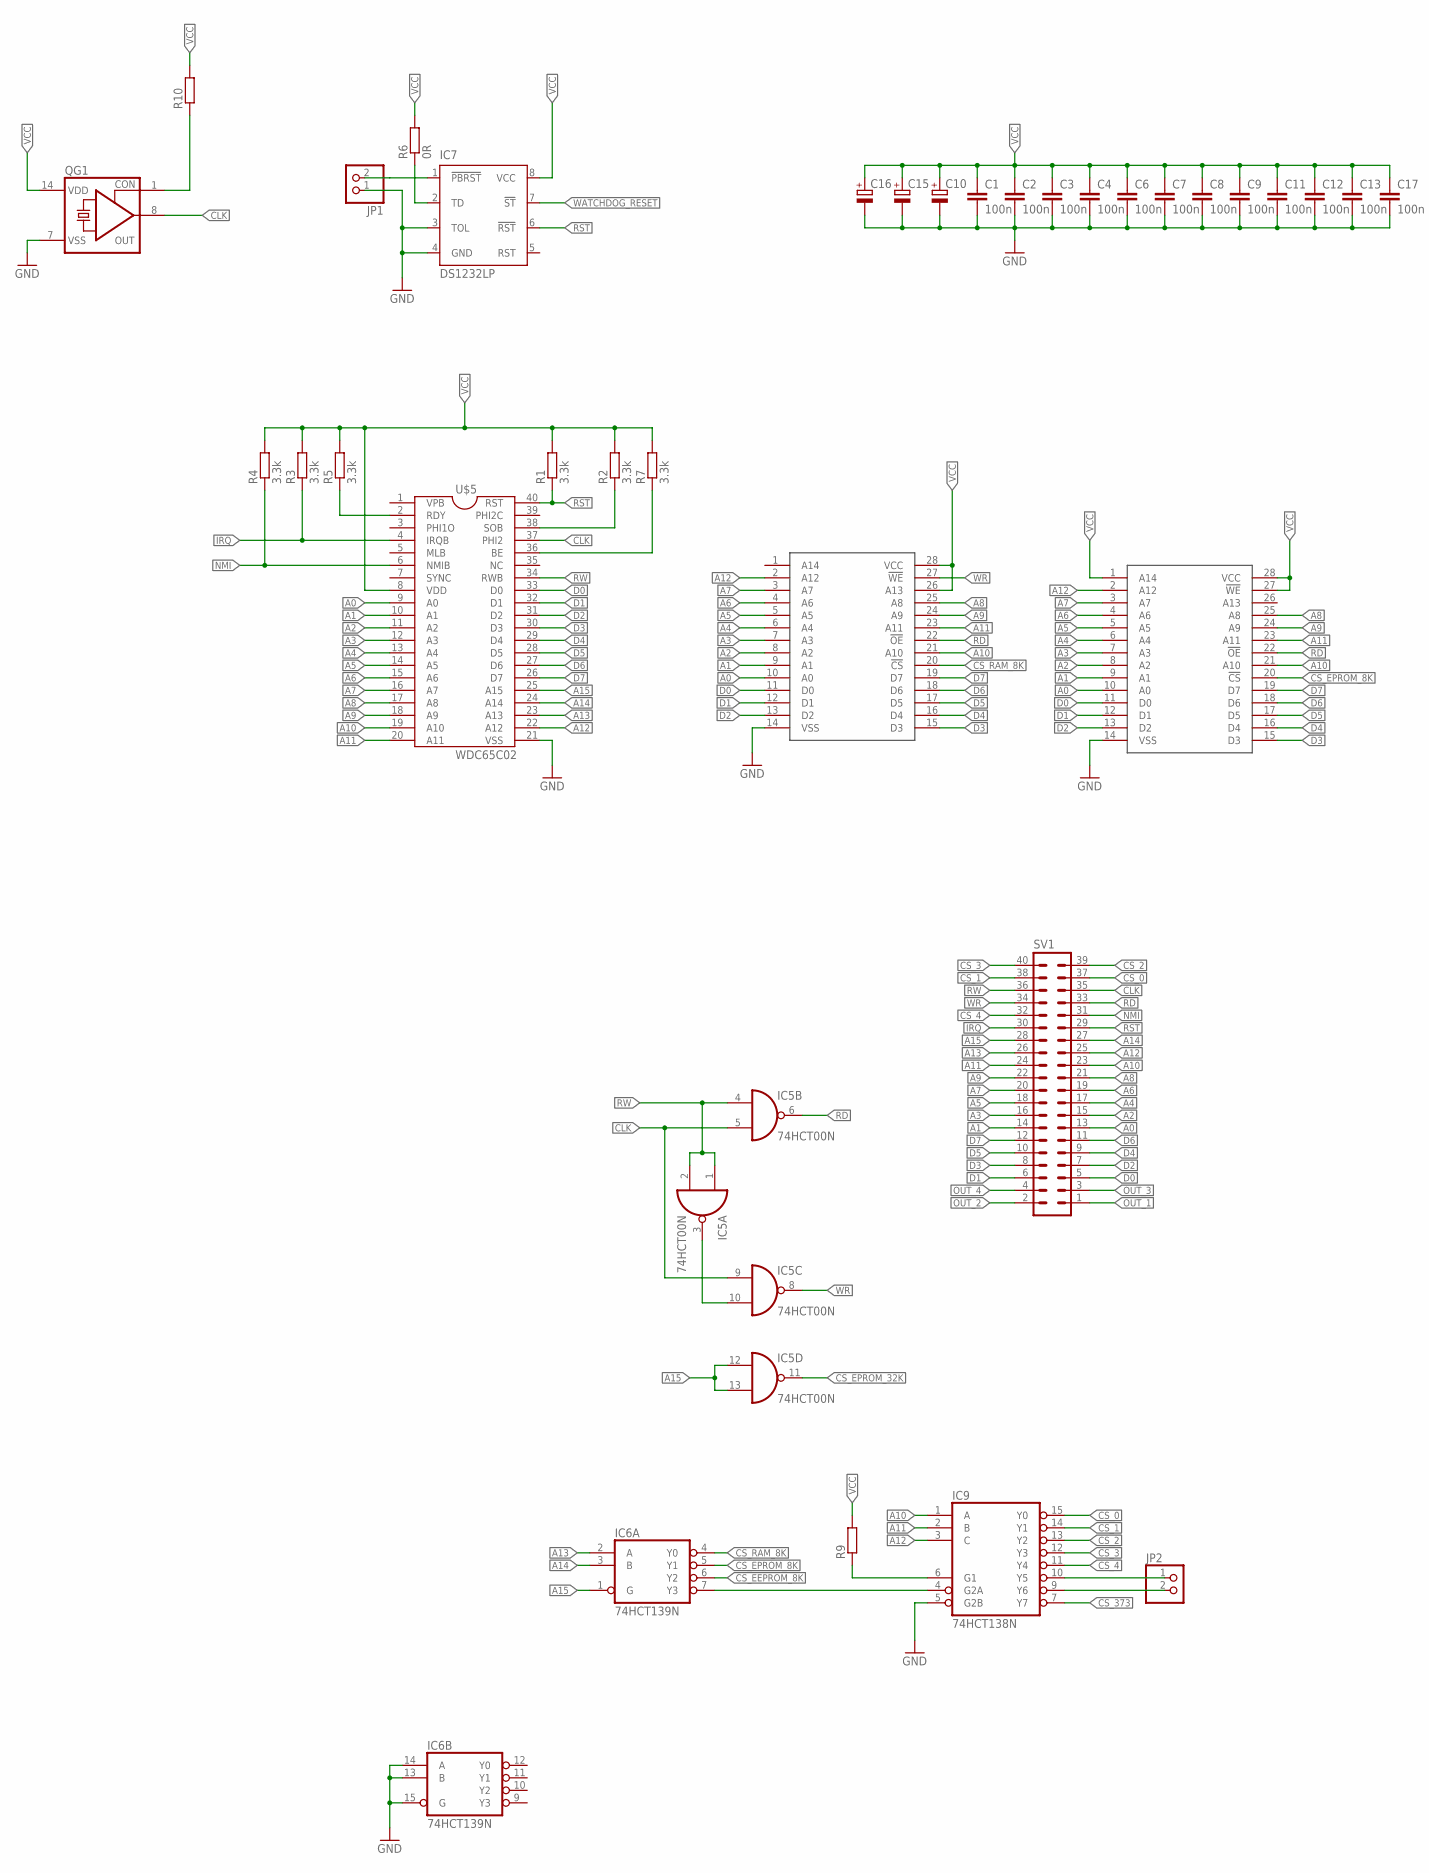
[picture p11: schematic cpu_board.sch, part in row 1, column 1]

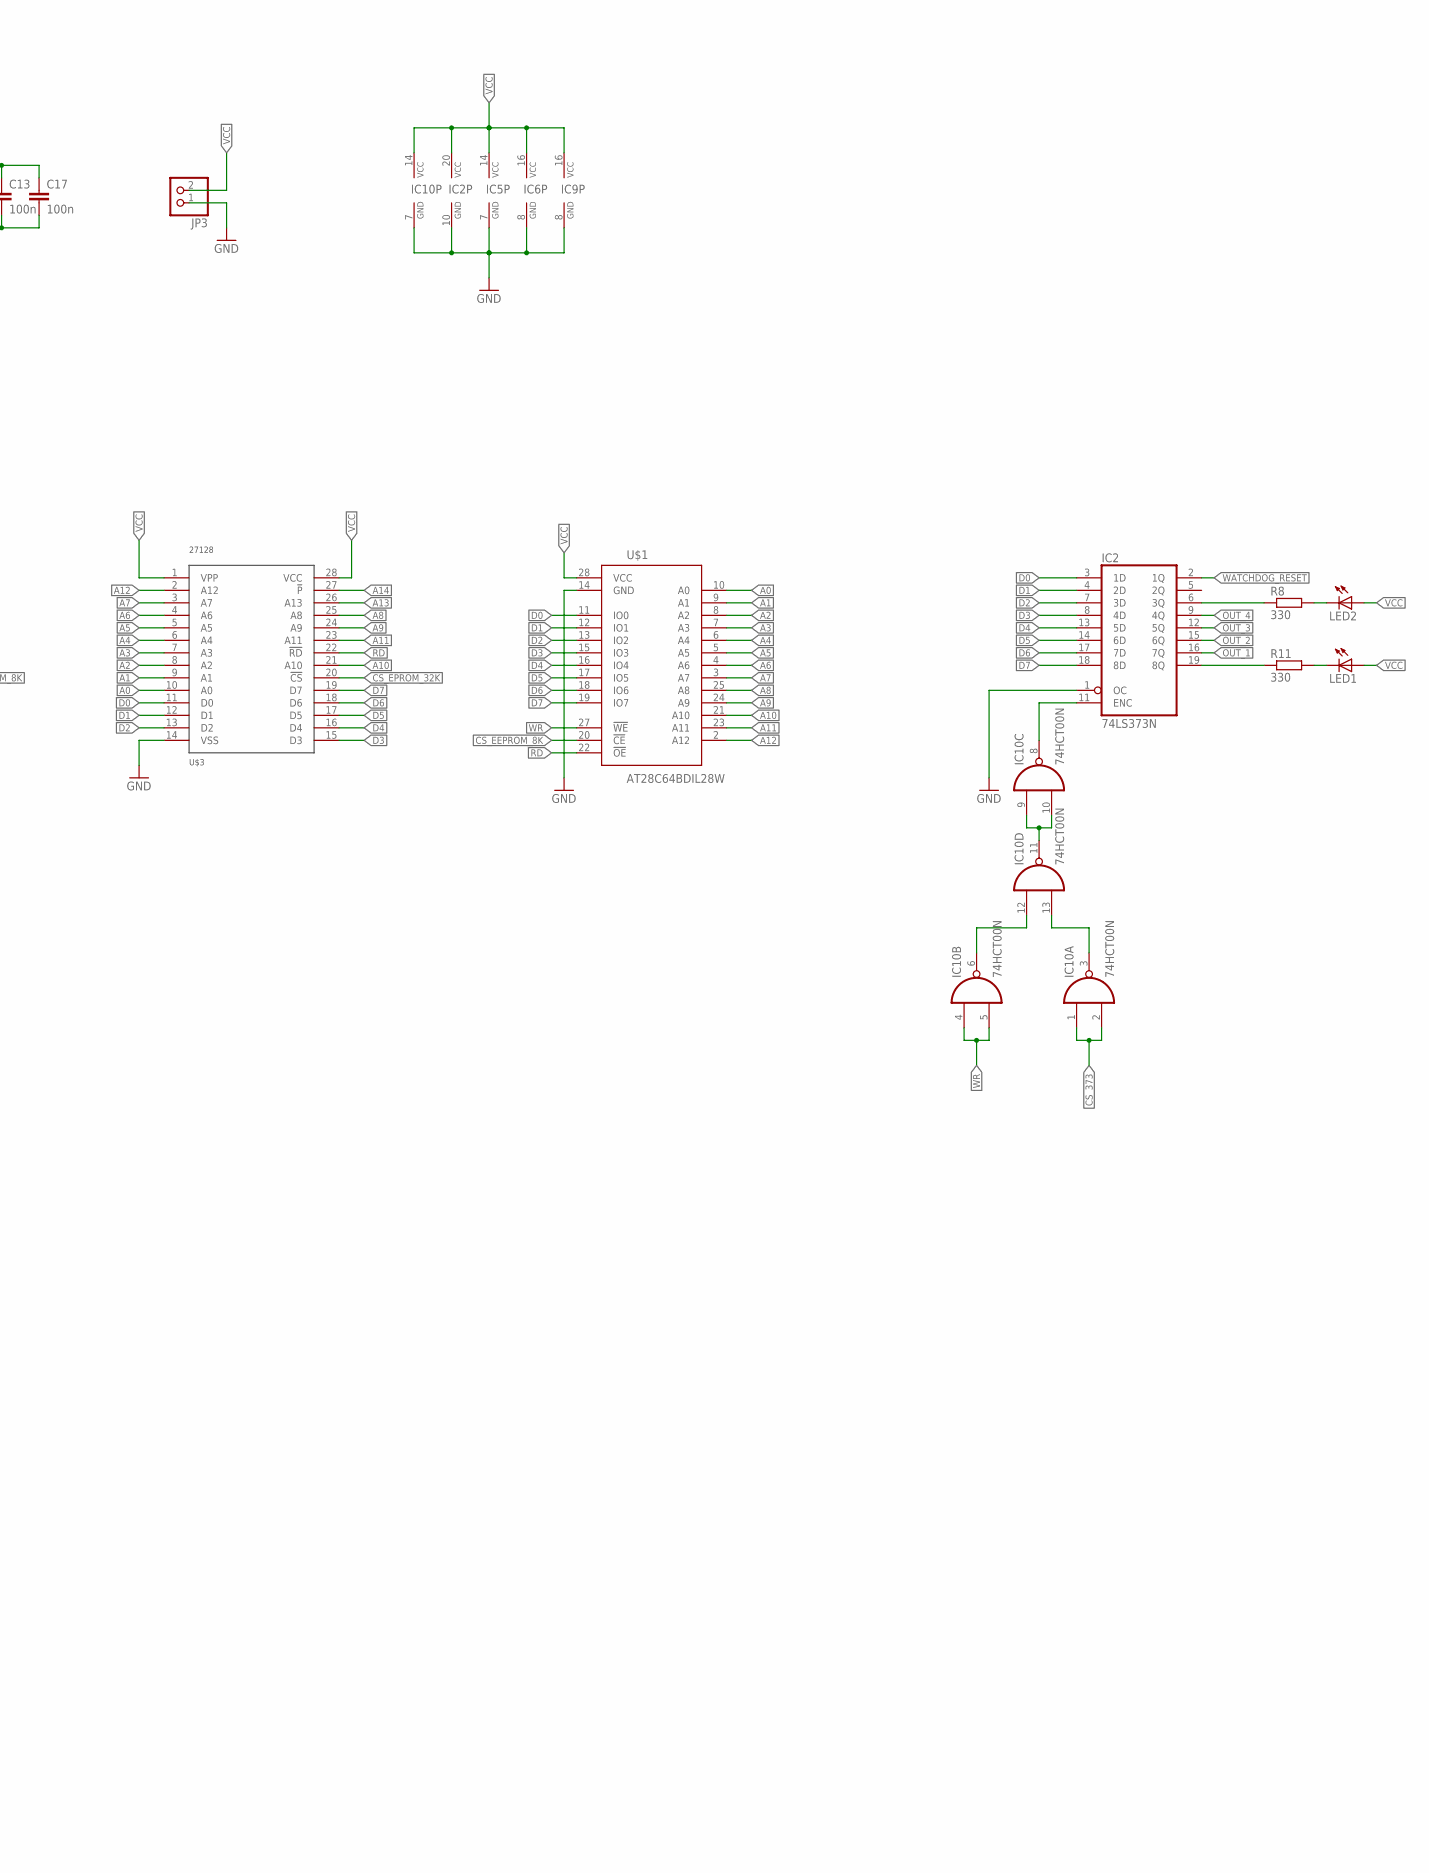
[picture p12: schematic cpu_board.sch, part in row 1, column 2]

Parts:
C1, C2, C3, C4, C6, C7, C8, C9, C17: 100n; C1206
C10: CPOL-EUE5-10.5; E5-10,5
C11, C12, C13: 100n; C0805
C15, C16: CPOL-EUSMCB; SMC_B
IC2: 74LS373N; DIL20
IC5, IC10: 74HCT00N; DIL14
IC6: 74HCT139N; DIL16
IC7: DS1232LP; DIL08
IC9: 74HCT138N; DIL16
JP1, JP2: PINHD-1X2; 1X02
JP3: PINHD-1X2/90; 1X02/90
LED1, LED2: LED5MM
QG1: CRYSTAL_RES-SG51; SG51
R1, R2, R3, R4, R5, R7: 3.3k; R1206
R6: 0R; R1206
R8, R11: 330; R1206
R9: R-EU_0204/7; 0204/7
R10: R-EU_R1206; R1206
SV1: ML40L
U$1: AT28C64BDIL28W; DIL28-6
U$2, U$4: 62256; DIL28-6
U$3: 27128; DIL28
U$5: WDC65C02; DIL40

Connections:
A0: SV1.13, U$1.10 (A0), U$2.10 (A0), U$3.10 (A0), U$4.10 (A0), U$5.9 (A0)
A1: SV1.14, U$1.9 (A1), U$2.9 (A1), U$3.9 (A1), U$4.9 (A1), U$5.10 (A1)
A2: SV1.15, U$1.8 (A2), U$2.8 (A2), U$3.8 (A2), U$4.8 (A2), U$5.11 (A2)
A3: SV1.16, U$1.7 (A3), U$2.7 (A3), U$3.7 (A3), U$4.7 (A3), U$5.12 (A3)
A4: SV1.17, U$1.6 (A4), U$2.6 (A4), U$3.6 (A4), U$4.6 (A4), U$5.13 (A4)
A5: SV1.18, U$1.5 (A5), U$2.5 (A5), U$3.5 (A5), U$4.5 (A5), U$5.14 (A5)
A6: SV1.19, U$1.4 (A6), U$2.4 (A6), U$3.4 (A6), U$4.4 (A6), U$5.15 (A6)
A7: SV1.20, U$1.3 (A7), U$2.3 (A7), U$3.3 (A7), U$4.3 (A7), U$5.16 (A7)
A8: SV1.21, U$1.25 (A8), U$2.25 (A8), U$3.25 (A8), U$4.25 (A8), U$5.17 (A8)
A9: SV1.22, U$1.24 (A9), U$2.24 (A9), U$3.24 (A9), U$4.24 (A9), U$5.18 (A9)
A10: IC9.1 (A), SV1.23, U$1.21 (A10), U$2.21 (A10), U$3.21 (A10), U$4.21 (A10), U$5.19 (A10)
A11: IC9.2 (B), SV1.24, U$1.23 (A11), U$2.23 (A11), U$3.23 (A11), U$4.23 (A11), U$5.20 (A11)
A12: IC9.3 (C), SV1.25, U$1.2 (A12), U$2.2 (A12), U$3.2 (A12), U$4.2 (A12), U$5.22 (A12)
A13: IC6.2 (A), SV1.26, U$3.26 (A13), U$5.23 (A13)
A14: IC6.3 (B), SV1.27, U$3.27 (!P), U$5.24 (A14)
A15: IC5.12 (I0), IC5.13 (I1), IC6.1 (G), SV1.28, U$5.25 (A15)
CLK: IC5.5 (I1), IC5.9 (I0), QG1.8 (OUT), SV1.35, U$5.37 (PHI2)
CS_0: IC9.15 (Y0), SV1.37
CS_1: IC9.14 (Y1), SV1.38
CS_2: IC9.13 (Y2), SV1.39
CS_3: IC9.12 (Y3), SV1.40
CS_4: IC9.11 (Y4), SV1.32
CS_373: IC9.7 (Y7), IC10.1 (I0), IC10.2 (I1)
CS_EEPROM_8K: IC6.6 (Y2), U$1.20 (!CE)
CS_EPROM_8K: IC6.5 (Y1), U$2.20 (!CS)
CS_EPROM_32K: IC5.11 (O), U$3.20 (!CS)
CS_RAM_8K: IC6.4 (Y0), U$4.20 (!CS)
D0: IC2.3 (1D), SV1.5, U$1.11 (IO0), U$2.11 (D0), U$3.11 (D0), U$4.11 (D0), U$5.33 (D0)
D1: IC2.4 (2D), SV1.6, U$1.12 (IO1), U$2.12 (D1), U$3.12 (D1), U$4.12 (D1), U$5.32 (D1)
D2: IC2.7 (3D), SV1.7, U$1.13 (IO2), U$2.13 (D2), U$3.13 (D2), U$4.13 (D2), U$5.31 (D2)
D3: IC2.8 (4D), SV1.8, U$1.15 (IO3), U$2.15 (D3), U$3.15 (D3), U$4.15 (D3), U$5.30 (D3)
D4: IC2.13 (5D), SV1.9, U$1.16 (IO4), U$2.16 (D4), U$3.16 (D4), U$4.16 (D4), U$5.29 (D4)
D5: IC2.14 (6D), SV1.10, U$1.17 (IO5), U$2.17 (D5), U$3.17 (D5), U$4.17 (D5), U$5.28 (D5)
D6: IC2.17 (7D), SV1.11, U$1.18 (IO6), U$2.18 (D6), U$3.18 (D6), U$4.18 (D6), U$5.27 (D6)
D7: IC2.18 (8D), SV1.12, U$1.19 (IO7), U$2.19 (D7), U$3.19 (D7), U$4.19 (D7), U$5.26 (D7)
GND: C1.2, C2.2, C3.2, C4.2, C6.2, C7.2, C8.2, C9.2, C10.-, C11.2, C12.2, C13.2, C15.-, C16.-, C17.2, IC2.1 (OC), IC2.10 (GND), IC5.7 (GND), IC6.8 (GND), IC6.13 (B), IC6.14 (A), IC6.15 (G), IC7.3 (TOL), IC7.4 (GND), IC9.5 (G2B), IC9.8 (GND), IC10.7 (GND), JP1.1, JP3.1, QG1.7 (VSS), U$1.14 (GND), U$2.14 (VSS), U$3.14 (VSS), U$4.14 (VSS), U$5.21 (VSS)
IRQ: R3.1, SV1.30, U$5.4 (IRQB)
unnamed: IC7.2 (TD), R6.1
unnamed: R2.1, U$5.38 (SOB)
unnamed: IC7.1 (!PBRST), JP1.2
unnamed: R7.1, U$5.36 (BE)
unnamed: R5.1, U$5.2 (RDY)
unnamed: IC2.19 (8Q), R11.1
unnamed: QG1.1 (CON), R10.1
unnamed: IC6.7 (Y3), IC9.4 (G2A)
unnamed: LED1.K (C), R11.2
unnamed: IC2.11 (ENC), IC10.8 (O)
unnamed: IC10.9 (I0), IC10.10 (I1), IC10.11 (O)
unnamed: IC10.3 (O), IC10.13 (I1)
unnamed: IC10.6 (O), IC10.12 (I0)
unnamed: IC2.6 (3Q), R8.1
unnamed: IC9.10 (Y5), JP2.1
unnamed: LED2.K (C), R8.2
unnamed: IC5.3 (O), IC5.10 (I1)
unnamed: IC9.6 (G1), R9.1
unnamed: IC9.9 (Y6), JP2.2
NMI: R4.1, SV1.31, U$5.6 (NMIB)
OUT_1: IC2.16 (7Q), SV1.1
OUT_2: IC2.15 (6Q), SV1.2
OUT_3: IC2.12 (5Q), SV1.3
OUT_4: IC2.9 (4Q), SV1.4
RD: IC5.6 (O), SV1.33, U$1.22 (!OE), U$2.22 (!OE), U$3.22 (!RD), U$4.22 (!OE)
RST: IC7.6 (!RST), R1.1, SV1.29, U$5.40 (RST)
RW: IC5.1 (I0), IC5.2 (I1), IC5.4 (I0), SV1.36, U$5.34 (RWB)
VCC: C1.1, C2.1, C3.1, C4.1, C6.1, C7.1, C8.1, C9.1, C10.+, C11.1, C12.1, C13.1, C15.+, C16.+, C17.1, IC2.20 (VCC), IC5.14 (VCC), IC6.16 (VCC), IC7.8 (VCC), IC9.16 (VCC), IC10.14 (VCC), JP3.2, LED1.A, LED2.A, QG1.14 (VDD), R1.2, R2.2, R3.2, R4.2, R5.2, R6.2, R7.2, R9.2, R10.2, U$1.28 (VCC), U$2.1 (A14), U$2.27 (!WE), U$2.28 (VCC), U$3.1 (VPP), U$3.28 (VCC), U$4.26 (A13), U$4.28 (VCC), U$5.8 (VDD)
WATCHDOG_RESET: IC2.2 (1Q), IC7.7 (!ST)
WR: IC5.8 (O), IC10.4 (I0), IC10.5 (I1), SV1.34, U$1.27 (!WE), U$4.27 (!WE)



Board: 2 copper layers, 151.4 x 117.5 mm, 44 parts (24 on the bottom side), 67 nets.

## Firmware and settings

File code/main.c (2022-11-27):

#include <stdio.h>
#include <stdint.h>
#include <stdlib.h>
#include <string.h>
#include <6502.h>
#include "delay.h"
#include "m6242.h"
#include "mc6840.h"
#include "mos6551.h"
#include "spo256.h"
#include "io.h"

//0x6000 - CS0
//		0x6000 - UART
//		0x6100 - TIMER
//		0x6200 - IN PORT (status flags)
//		0x6300 - SP0
//0x6400 - CS1		DISPLAY BOARD
//		0x6400 - RTC
//		0x6600 - DIG0 (write) / BUTTONS (read)
//		0x6601 - DIG1 (write)
//		0x6602 - DIG2 (write)
//		0x6603 - DIG3 (write)
//		0x6680 - NOT USED
//		0x6700 - NOT USED
//		0x6780 - NOT USED

//0x6800 - CS2
//0x6C00 - CS3
//0x7000 - CS4
//0x7400 - CS5
//0x7800 - CS6
//0x7C00 - CS7

//0x7C00 - 373
//#define PORT (*(volatile uint8_t*)0x7C00)
//#define BTNS (*(volatile uint8_t*)0x6600)
//#define FLAGS (*(volatile uint8_t*)0x6200)
#define PUNS (uint16_t*)0x2000

typedef enum {SHOW_TIME, SHOW_SECONDS, SHOW_DATE, SHOW_YEAR} state_t;
state_t state = SHOW_TIME; 

const uint8_t spo_msg[12] = {pHH1, pEH, pLL, pOW, pPA5, pWW, pER1, pLL, pPA2, pDD1, pPA3, pSTOP}; // Hello World

uint8_t spo_buff[256];

uint32_t last_state_change = 0;
uint32_t last_uptime = 0;
uint8_t wdt_timer = 0;
uint8_t blink_timer = 0;

char buffer[16];
static uint16_t *punptr;
static uint8_t *ptr;
static uint8_t len, tmp;

key_t key0, key1, key2, key3;

char* __fastcall__ utoa (unsigned val, char* buf, int radix);
void* __fastcall__ memcpy (void* dest, const void* src, size_t count);
size_t __fastcall__ strlen (const char* s);

void update_display (void);
void key0_func (void);
void key1_func (void);
void key2_func (void);
void key3_func (void);


int main (void) {

	port_write(0xC1);
	
	punptr = PUNS;
	
    mc6840_init();
    m6242_init();
    mos6551_init();
	
	CLI();
	
	key_init(&key0, BTN0, key0_func);
	key_init(&key1, BTN1, key1_func);
	key_init(&key2, BTN2, key2_func);
	key_init(&key3, BTN3, key3_func);
    
    spo256_play(spo_msg);
	mos6551_puts("Start!\r\n");
	
	while(1) {
		
		if (uptime() != last_uptime) {					// New tick from interrupt
			last_uptime = uptime();						// Clear it first
			update_display();       
		}
        
        if ( (uint8_t) (millis() - wdt_timer) >= 20) {       //20x12.5ms
			wdt_timer = millis();
			feed_hungry_watchdog();							//Reset watchdog
		}
		
        if ( (uint8_t) (millis() - blink_timer) >= 80) {       //80x12.5ms (1s)
			blink_timer = millis();
			//port_tgl(0x84);									//Toggle both LEDs
		}		
		
		key_update(&key0);
		key_update(&key1);
		key_update(&key2);
		key_update(&key3);
		mos6551_handle_rx();        
        spo256_handle();
        dcf_handle();
	}
	
	return 0;
}


void update_display (void) {
	static uint8_t dot = 0;
	
	switch(state) {
		case SHOW_TIME:
		m6242_read_time_raw(buffer);
		disp_write(buffer, (dot ? DOT1 : 0x00) );
		dot = !dot;
		break;
		
		case SHOW_SECONDS:
		m6242_read_time_raw(buffer);
		buffer[0] = 16;		// This digit is empty
		buffer[1] = 16;		// This digit is empty
		buffer[2] = buffer[4];
		buffer[3] = buffer[5];
		disp_write(buffer, DOT1);
		if ( (uint32_t) (uptime() - last_state_change) >= 60 ) { state = SHOW_TIME; }
		break;
		
		case SHOW_DATE:
		m6242_read_date_raw(buffer);
		disp_write(buffer, DOT1);
		if ( (uint32_t) (uptime() - last_state_change) >= 60 ) { state = SHOW_TIME; }
		break;
		
		case SHOW_YEAR:
		m6242_read_date_raw(buffer);
		buffer[0] = 2;
		buffer[1] = 0;
		buffer[2] = buffer[4];
		buffer[3] = buffer[5];
		disp_write(buffer, DOT3);
		if ( (uint32_t) (uptime() - last_state_change) >= 60 ) { state = SHOW_TIME; }
		break;
	}    	
}


void key0_func (void) {
	state++;
	if (state > SHOW_YEAR) state = SHOW_TIME;
	last_state_change = uptime();
	update_display();
}

void key1_func (void) {
	spo256_play((uint8_t*)*punptr);
	punptr++;
	if (*punptr == 0x00) punptr = PUNS;
	//spo256_play(spo_msg);
}

void key2_func (void) {
    ptr = spo_buff;
    
	//READ TIME
	m6242_read_time_raw(buffer);
    
    //Prepare hour phonemes
	tmp = (buffer[0] * 10) + buffer[1];
	if (tmp < 20) {
		memcpy(ptr, spo_numbers[tmp], len = spolen(spo_numbers[tmp]));
		ptr += len;
	}
	else {
        if (buffer[0] > 0) {
			memcpy(ptr, spo_tens[buffer[0]], len = spolen(spo_tens[buffer[0]]));
			ptr += len;
		}
        if (buffer[1] > 0) { 
			memcpy(ptr, spo_numbers[buffer[1]], len = spolen(spo_numbers[buffer[1]]));
			ptr += len;
		}		
	}
    
    *ptr = pPA3;
    ptr++;
	memcpy(ptr, spo_hour, len = spolen(spo_hour));
	ptr += len;
    if (tmp != 1) {
        *ptr = pZZ;
        ptr++;
    }    
    *ptr = pPA3;
    ptr++;	    
    
    //Prepare minutes phonemes
    tmp = (buffer[2] * 10) + buffer[3];
    if (tmp < 20) {
		memcpy(ptr, spo_numbers[tmp], len = spolen(spo_numbers[tmp]));
		ptr += len;
    }
    else {
        if (buffer[2] > 0) {
			memcpy(ptr, spo_tens[buffer[2]], len = spolen(spo_tens[buffer[2]]));
			ptr += len;
		}
        if (buffer[3] > 0) { 
			memcpy(ptr, spo_numbers[buffer[3]], len = spolen(spo_numbers[buffer[3]]));
			ptr += len;
		}
    }
    
    //Prepare seconds phonemes
    *ptr = pPA3;
    ptr++;
	memcpy(ptr, spo_minute, len = spolen(spo_minute));
	ptr += len;
    if (tmp != 1) {
        *ptr = pZZ;
        ptr++;
    }    
    *ptr = pPA3;
    ptr++;	        
    
    tmp = (buffer[4] * 10) + buffer[5];
    if (tmp < 20) {
        memcpy(ptr, spo_numbers[tmp], len = spolen(spo_numbers[tmp]));
        ptr += len;
    }
    else {
        if (buffer[4] > 0) { 
			memcpy(ptr, spo_tens[buffer[4]], len = spolen(spo_tens[buffer[4]]));
			ptr += len;
		}
        if (buffer[5] > 0) { 
			memcpy(ptr, spo_numbers[buffer[5]], len = spolen(spo_numbers[buffer[5]]));
			ptr += len;
		}
    }
    
    *ptr = pPA5;
    ptr++;
	memcpy(ptr, spo_second, len = spolen(spo_second));
	ptr += len;
    if (tmp != 1) {
        *ptr = pZZ;
        ptr++;
    }
    *ptr = pPA3;
    ptr++;	      
    *ptr = pSTOP;	
	spo256_play(spo_buff);
}


void key3_func (void) {
	ptr = spo_buff;
	//READ DATE
	m6242_read_date_raw(buffer);

    //Prepare fay of the week phonemes
    /*
    memcpy(ptr, spo_weekdays[buffer[6]], len = spolen(spo_weekdays[buffer[6]]));
    ptr += len;
    *ptr = pPA5;
    ptr++;
    */
    
    //Prepare month phonemes
    tmp = (buffer[2] * 10) + buffer[3];
    tmp--;
    memcpy(ptr, spo_months[tmp], len = spolen(spo_months[tmp]));
    ptr += len;
    *ptr = pPA5;
    ptr++;

    //Prepare day of month phonemes
	tmp = (buffer[0] * 10) + buffer[1];
	if (tmp < 6) {
		memcpy(ptr, spo_numerals[tmp], len = spolen(spo_numerals[tmp]));
		ptr += len;
	}
	else if (tmp < 20) {
		memcpy(ptr, spo_numbers[tmp], len = spolen(spo_numbers[tmp]));
		ptr += len;
		*ptr = pTH;
		ptr++;
	}
	else {
        if (buffer[0] > 0) {
			memcpy(ptr, spo_tens[buffer[0]], len = spolen(spo_tens[buffer[0]]));
			ptr += len;
		}
        if (buffer[1] > 0) { 
			if (buffer[1] < 6) {
				memcpy(ptr, spo_numerals[buffer[1]], len = spolen(spo_numerals[buffer[1]]));
				ptr += len;
			}
			else {
				memcpy(ptr, spo_numbers[buffer[1]], len = spolen(spo_numbers[buffer[1]]));
				ptr += len;
				*ptr = pTH;
				ptr++;								
			}
		}		
	}
	
    *ptr = pPA5;
    ptr++;	
    
    //Prepare year phonemes      
    //We assume the years is > 2000
    memcpy(ptr, spo_numbers[2], len = spolen(spo_numbers[2]));      //We need "two" to be said first
    ptr += len;
    memcpy(ptr, spo_thousand, len = spolen(spo_thousand));          //Then "thousand" needs to be said
    ptr += len;
    *ptr = pPA3;
    ptr++;
    //Phonemes for last two digits of the year
    tmp = (buffer[4] * 10) + buffer[5];
    if (tmp < 20) {
        memcpy(ptr, spo_numbers[tmp], len = spolen(spo_numbers[tmp]));
        ptr += len;
    }
    else {
        if (buffer[4] > 0) { 
			memcpy(ptr, spo_tens[buffer[4]], len = spolen(spo_tens[buffer[4]]));
			ptr += len;
		}
        if (buffer[5] > 0) { 
			memcpy(ptr, spo_numbers[buffer[5]], len = spolen(spo_numbers[buffer[5]]));
			ptr += len;
		}
    }
    
    *ptr = pPA5;
    ptr++;	      
    *ptr = pSTOP;    
	spo256_play(spo_buff);
}

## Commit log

2020-09-18 PCB added
    [cpu_board.brd, cpu_board.sch, digits.brd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]
2021-03-22 Timers fixed
2021-03-22 Timers and sound
2021-03-25 PCB updated
    [sp0256_dcf77.brd, sp0256_dcf77.sch]
2022-11-24 millis() usadge adapted to 12.5 ms systick
2022-11-24 DCF77 adapted to 12.5 ms systick interrupt
2022-11-27 Optimization relading timer every time not needed

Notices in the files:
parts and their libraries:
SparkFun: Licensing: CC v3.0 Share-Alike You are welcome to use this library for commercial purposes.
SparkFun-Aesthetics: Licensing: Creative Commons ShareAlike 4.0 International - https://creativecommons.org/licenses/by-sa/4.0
